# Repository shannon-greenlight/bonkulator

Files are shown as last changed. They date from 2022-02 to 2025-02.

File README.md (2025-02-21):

# Bonkulator
# The Bonkulator has been replaced by Thor's Arsenal

The Bonkulator is a Eurorack module that fits into a 3U x 14HP slot. It features 8 programmable outputs and 6 programmable inputs. The front-panel user controls consist of a 128×64 pixel 2-color OLED display, a rotary encoder for adjusting parameters and a button for each trigger and output.

# main_board, panel

These repos contain the materials needed to construct the Bonkulator main board and the front panel.
The files are for KiCAD 6.0. Go to the Greenlight Kicad repo to get the needed libraries.
The gerber files work with JLCPC and will most likely work with other board manufacturers.

Assembly instructions are in main_board\fab\bonkulator_assembly.docx.

When using the JLCPCB assembly service, the BOM is split into 3 parts.

- bom/lcsc/bonkulator_bom.xlsx : The parts to be assembled by JLCPCB
- bom/digi-key/bonkulator_bom.xlsx : The remaining parts to be assembled by user
- bom/other/other_bom.xlsx : The parts that must be bought from sources other than JLCPCB and Digi-Key

Also, when an assembly service is used, a component position file is required. This file's path is: fab/Bonkulator_cpl.xlsx

notes: The bom and cpl files are auto-generated from the csv BOM files produced by KiCAD. You will need to refresh the data when changes to the schematic that affect the BOM or changes to the board layout occur.
If they exist, the extra parts and additional data fields that appear on the schematic help to produce the different BOM files. They must be maintained for these BOMs to come out right.

# code

This repository contains the elements needed to build code for the Bonkulator.

# BonkDaddy

The Bonk Daddy is an addition to the Bonkulator that provides these benefits:

- Front Panel USB access
- Power sensing shuts off USB to Arduino when synth power is off
- Reset switch
- USB Power indicator
- Trig In indicators
- Boot Loader indicator
- Extremely useful to those who use Terminal Remote mode

The folder structure of the Bonk Daddy is similar to the Bonkulator Hardware folder, main_board. Currently there is no support for assembly service.

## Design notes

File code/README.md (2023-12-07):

# Bonkulator-Code

This repository contains the elements needed to build code for the Bonkulator.
The code is for the Arduino RP2040 Connect and is found in the code/Bonkulator folder. Make sure to get the required libraries from the Arduino-Libs repo.
The code package is designed to be stand-alone and work with any IDE. You don't need the Arduino IDE. However, it will work with the Arduino IDE if you want to use it.

Build files are provided for Windows and Mac.

Here is a list of the batch and shell files:

- make.bat, make.sh ... compiles the code
- make_n_load.bat, make_n_load.sh ... calls make then uploads the code to the Bonkulator
- load_recent.bat, load_recent.sh ... loads most recent compile
- list_ports.bat, list_ports.sh ... lists available COM ports
- release.bat, release.sh ... used to create release, updating the release number in the code and create zip archives in the releases folder

Folders:

- out ... this folder must be created. It holds compile output
- releases ... this folder contains all of the archived releases
- updater ... this folder contains files needed by users to update their modules. This is what is zipped into the archive files.
- bin ... this folder contains executables for the Mac
- Bonkulator ... folder where the code exists
- secrets_example ... copy this folder to code/Bonkulator and rename it: secrets. Edit secrets.h to enter your preferred WiFi network and password.

The Arduino libraries from the Arduino-Libs repo must be included. Put them in the code/Bonkulator folder in a folder named 'libraries'.
Copy the entire contents of Arduino-Libs, not the folder itself. You can clone the libraries directly.

1. Go to the code/Bonkulator folder and open a power shell if on Windows, or open a Terminal if you are on the Mac.
2. Type: git clone https://github.com/shannon-greenlight/Arduino-Libs.git
3. Rename the resulting Arduino-Libs folder : libraries.
4. Keep this folder up to date using: git pull.

If you are using a Mac, you must call the .sh files from a Terminal window. Use the form ./filename.sh to execute the .sh file.
Use the following instructions to open a Terminal window in the code folder:

1. Open Finder.
2. Navigate to the directory where you want to open the Terminal.
3. Click to select the folder.
4. From the menu bar at the top of the screen, click on Finder.
5. In the dropdown menu, hover over Services.
6. In the Services menu, click on New Terminal at Folder.

This will open a new Terminal window that's already navigated to the directory you selected in Finder. If you don't see the New Terminal at Folder option, you may need to enable it in System Preferences -> Keyboard -> Shortcuts -> Services.

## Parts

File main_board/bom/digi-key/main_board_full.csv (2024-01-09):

Reference | Quantity | Value | Digi-Key Part #
A1, | 1 | Arduino_Nano_RP2040_Connect | 1050-ABX00053-ND
C1, C2, | 2 | 100uF | 399-A768EB107M1ELAE036DKR-ND
C3, C4, C5, C6, C8, C9, C14, C15, C16, C17, C18, C19, C20, C21, C22, C23, C24, C25, C27, C28, C29, C30, C32, C33, C34, C35, C36, C37, C38, C39, C40, C41, C42, C52, C53, C54, C55, | 37 | 100nF | 478-10836-1-ND
C7, C31, C43, | 3 | 1uF | 1276-1029-1-ND
C11, C12, C13, C26, C44, C45, C46, C47, C48, C49, C50, C51, | 12 | 10nF | 311-1136-1-ND
D1, D2, D3, D4, D5, D6, D7, D8, D13, D14, D15, D16, D17, D18, D39, D40, D41, D42, D45, D46, | 20 | 1N5819 | 478-7800-1-ND
D9, D19, D20, D21, D22, D23, D24, D29, D30, D31, D32, | 11 | BLUE LED | 732-11401-ND
D10, | 1 | YELLOW LED | 732-5010-ND
D11, D25, D26, D27, D28, D33, D34, D35, D36, D37, D38, | 11 | RED LED | 732-5005-ND
D12, | 1 | GREEN LED | 732-5007-ND
D43, D44, | 2 | 7.5V | DDZ7V5CDICT-ND
J1, J2, J3, J4, J8, J9, J10, J11, J12, J13, J14, J15, J16, J17, | 14 | 3.5mm Jack | WM17366-ND
J5, | 1 | Display Header | SAM1011-04-ND
J6, | 1 | EU Power | S2011EC-05-ND
J7, | 1 | Expansion Header | S2011EC-05-ND
J18, J19, | 2 | Conn_01x15_Female | S7048-ND
J20, | 1 | Conn_01x02_Male | 609-4938-ND
J21, | 1 | OLED Pins | 732-5317-ND
N1, N2, N3, N4, N5, N6, | 6 | Nut | 36-4687-ND
Q1, | 1 | MMBT3904 | 4878-MMBT3904CT-ND
R1, R2, R3, R4, R32, R37, R38, R39, R56, R57, R66, R67, R68, R69, R70, R71, R72, R97, R98, R99, R100, R125, R126, R127, R128, R141, | 26 | 10K | 13-RC0805JR-1010KLCT-ND
R5, R6, R7, R8, | 4 | 1K | RNCP0805FTD1K00CT-ND
R9, | 1 | 200K .1% | P200KDACT-ND
R10, | 1 | 68K | 311-68KARCT-ND
R11, R12, R13, R14, R15, R16, R17, R18, R19, R40, R41, R42, R43, R44, R45, R46, R47, R61, R62, R63, R64, R65, R73, R74, R75, R78, R142, R143, | 28 | 100K .1% | YAG1759CT-ND
R20, R21, R22, R23, R48, R49, R50, R51, R58, | 9 | 33K | RMCF0805JT33K0CT-ND
R24, R25, R26, R27, R52, R53, R54, R55, | 8 | 332K .1% | P332KDACT-ND
R28, R33, | 2 | 30.1K .1% | P30.1KDACT-ND
R29, R31, R34, R36, | 4 | 10K .1% | P10KDACT-ND
R30, R35, | 2 | 4.7K | RMCF0805FT4K70CT-ND
R59, R60, | 2 | 680 | 311-680ARCT-ND
R76, R79, R80, R81, R82, | 5 | 1K | RNCP0603FTD1K00CT-ND
R77, | 1 | 23.7K 1% | RMCF0603FT23K7CT-ND
RV9, | 1 | 10K | 3224W-1-103GCT-ND
SC1, SC2, SC3, SC4, | 4 | Screw | 145-50M025045P006-ND
SO1, SO2, SO3, SO4, SO5, SO6, SO7, SO8, SO9, SO10, SO11, SO12, SO13, SO14, SO15, SO16, SO17, SO18, SO19, SO20, SO21, SO22, SO23, SO24, | 24 | LED_Standoff | 732-11607-ND
SO25, SO26, SO27, SO28, | 4 | Board Standoff | 732-13063-ND
SO29, SO30, | 2 | DisplayStandoff | 732-13055-ND
SW1, SW2, SW3, SW4, SW6, SW7, SW8, SW9, SW10, SW11, SW12, SW13, SW14, SW15, SW16, SW17, | 16 | Push Button | 450-1643-ND
SW5, | 1 | Adj | 987-1187-ND
TP1, TP2, | 2 | TestPoint | 36-5006-ND
TP3, TP4, | 2 | TestPoint | 36-5002-ND
U1, U4, U9, U10, U12, U14, U17, U18, | 8 | TL072CDR | 296-1282-1-ND
U2, U5, U8, U19, | 4 | TL072CDR | 296-1282-1-ND
U6, | 1 | AD5328 | 505-AD5328ARUZ-REEL7CT-ND
U11, | 1 | ADS1015IDGS | 296-25227-1-ND
U13, U24, | 2 | DG412DY-E3 | DG412DY-E3-ND
U15, | 1 | AS431HANTR | AS431HANTR-G1DICT-ND
U16, | 1 | MB85RC256 | 865-1261-1-ND
U21, | 1 | MCP23008-xSS | MCP23008-E/SS-ND

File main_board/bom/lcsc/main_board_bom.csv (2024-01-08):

Designator | Comment | Footprint | JLCPCBPart#
C1, C2, | 100uF | Capacitor_SMD:CP_Elec_6.3x5.4_Nichicon | C2887272
C3, C4, C5, C6, C8, C9, C14, C15, C16, C17, C18, C19, C20, C21, C22, C23, C24, C25, C27, C28, C29, C30, C32, C33, C34, C35, C36, C37, C38, C39, C40, C41, C42, C52, C53, C54, C55, | 100nF | Capacitor_SMD:C_0805_2012Metric_Pad1.18x1.45mm_HandSolder | C49678
C7, C31, C43, | 1uF | Capacitor_SMD:C_0805_2012Metric_Pad1.18x1.45mm_HandSolder | C28323
C11, C12, C13, C26, C44, C45, C46, C47, C48, C49, C50, C51, | 10nF | Capacitor_SMD:C_0805_2012Metric_Pad1.18x1.45mm_HandSolder | C1710
D1, D2, D3, D4, D5, D6, D7, D8, D13, D14, D15, D16, D17, D18, D39, D40, D41, D42, D45, D46, | 1N5819 | Diode_SMD:D_0805_2012Metric_Pad1.15x1.40mm_HandSolder | C191023
D43, D44, | 7.5V | Diode_SMD:D_SOD-123 | C545306
J6, | EU Power | Connector_PinHeader_2.54mm:PinHeader_2x05_P2.54mm_Vertical | C492422
J7, | Expansion Header | Connector_PinHeader_2.54mm:PinHeader_2x05_P2.54mm_Vertical | C492422
J18, J19, | Conn_01x15_Female | sputterizer:ArduinoConnector | C2932676
J20, | Conn_01x02_Male | Connector_PinHeader_2.54mm:PinHeader_1x02_P2.54mm_Vertical | C492401
Q1, | MMBT3904 | Package_TO_SOT_SMD:SOT-23 | C20526
R1, R2, R3, R4, R32, R37, R38, R39, R56, R57, R66, R67, R68, R69, R70, R71, R72, R97, R98, R99, R100, R125, R126, R127, R128, R141, | 10K | Resistor_SMD:R_0805_2012Metric_Pad1.20x1.40mm_HandSolder | C17414
R5, R6, R7, R8, | 1K | Resistor_SMD:R_0805_2012Metric_Pad1.20x1.40mm_HandSolder | C17513
R9, | 200K .1% | Resistor_SMD:R_0805_2012Metric_Pad1.20x1.40mm_HandSolder | C332260
R10, | 68K | Resistor_SMD:R_0805_2012Metric_Pad1.20x1.40mm_HandSolder | C17801
R11, R12, R13, R14, R15, R16, R17, R18, R19, R40, R41, R42, R43, R44, R45, R46, R47, R61, R62, R63, R64, R65, R73, R74, R75, R78, R142, R143, | 100K .1% | Resistor_SMD:R_0805_2012Metric_Pad1.20x1.40mm_HandSolder | C122537
R20, R21, R22, R23, R48, R49, R50, R51, R58, | 33K | Resistor_SMD:R_0805_2012Metric_Pad1.20x1.40mm_HandSolder | C17633
R24, R25, R26, R27, R52, R53, R54, R55, | 332K .1% | Resistor_SMD:R_0805_2012Metric_Pad1.20x1.40mm_HandSolder | C2681637
R28, R33, | 30.1K .1% | Resistor_SMD:R_0805_2012Metric_Pad1.20x1.40mm_HandSolder | C374678
R29, R31, R34, R36, | 10K .1% | Resistor_SMD:R_0805_2012Metric_Pad1.20x1.40mm_HandSolder | C406725
R30, R35, | 4.7K | Resistor_SMD:R_0805_2012Metric_Pad1.20x1.40mm_HandSolder | C17673
R59, R60, | 680 | Resistor_SMD:R_0805_2012Metric_Pad1.20x1.40mm_HandSolder | C17798
R76, R79, R80, R81, R82, | 1K | Resistor_SMD:R_0603_1608Metric | C21190
R77, | 23.7K 1% | Resistor_SMD:R_0603_1608Metric | C227724
RV9, | 10K | Potentiometer_SMD:Potentiometer_Bourns_3224W_Vertical | C81348
TP1, TP2, | TestPoint | TestPoint:TestPoint_Keystone_5005-5009_Compact | C2906764
TP3, TP4, | TestPoint | TestPoint:TestPoint_Keystone_5000-5004_Miniature | C238123
U1, U4, U9, U10, U12, U14, U17, U18, | TL072CDR | Package_SO:SOIC-8-1EP_3.9x4.9mm_P1.27mm_EP2.29x3mm | C6961
U2, U5, U8, U19, | TL072CDR | Package_SO:SOIC-8_3.9x4.9mm_P1.27mm | C6961
U6, | AD5328 | Package_SO:TSSOP-16_4.4x5mm_P0.65mm | C29162
U11, | ADS1015IDGS | Package_SO:TSSOP-10_3x3mm_P0.5mm | C193969
U13, U24, | DG412DY-E3 | Package_SO:SOIC-16_3.9x9.9mm_P1.27mm | C45218
U15, | AS431HANTR | Package_TO_SOT_SMD:SOT-23 | C460669
U16, | MB85RC256 | Package_SO:SOIC-8_3.9x4.9mm_P1.27mm | C47538
U21, | MCP23008-xSS | Package_SO:SSOP-20_5.3x7.2mm_P0.65mm | C148011

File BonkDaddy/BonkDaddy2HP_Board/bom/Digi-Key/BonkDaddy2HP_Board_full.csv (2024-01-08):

Reference | Quantity | Value | Digi-Key Part #
C1, C3, | 2 | 1uF | 1276-1066-1-ND
D1, | 1 | RED LED | 732-5005-ND
D2, D4, | 2 | GREEN LED | 732-5008-ND
D3, | 1 | YELLOW LED | 732-5010-ND
D5, | 1 | BLUE LED | 160-1035-ND
J1, | 1 | EXP | S2011EC-05-ND
J2, | 1 | USB_B_Micro | 2073-USB3131-30-0230-ACT-ND
J3, | 1 | USB_A | UE27AE54100-ND
N1, N2, | 2 | Nut | 36-4687-ND
Q3, | 1 | 2N7002 | 4878-2N7002CT-ND
Q4, | 1 | MMBT3906 | MMBT3906LT1GOSCT-ND
R1, R2, R4, R5, | 4 | 620 | RMCF0805FT620RCT-ND
R3, | 1 | 1K | 311-1.00KCRCT-ND
R6, R9, | 2 | 10K | RMCF0805FT10K0CT-ND
R7, R8, | 2 | 30K | RMCF0805FT30K0CT-ND
SC1, SC2, | 2 | Screw | 145-50M025045G004-ND
SO1, SO2, | 2 | Stand-off | 1772-2756-ND
SW1, | 1 | Reset | 450-1940-ND
U1, | 1 | 74AHC14 | 296-9179-1-ND
W1, W2, | 2 | Washer | RPC3448-ND

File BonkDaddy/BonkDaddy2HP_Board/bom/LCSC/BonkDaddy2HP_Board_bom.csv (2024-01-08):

Designator | Comment | Footprint | JLCPCBPart#
C1, C3, | 1uF | Capacitor_SMD:C_0805_2012Metric | C28323
J1, | EXP | Connector_PinHeader_2.54mm:PinHeader_2x05_P2.54mm_Vertical_SMD | C124391
J3, | USB_A | sputterizer:USB_A_Amphenol_UE27AE54100_Vertical | C386737
Q3, | 2N7002 | Package_TO_SOT_SMD:SOT-23 | C8545
Q4, | MMBT3906 | Package_TO_SOT_SMD:SOT-23 | C266589
R1, R2, R4, R5, | 620 | Resistor_SMD:R_0805_2012Metric_Pad1.20x1.40mm_HandSolder | C17782
R3, | 1K | Resistor_SMD:R_0805_2012Metric_Pad1.20x1.40mm_HandSolder | C17513
R6, R9, | 10K | Resistor_SMD:R_0805_2012Metric_Pad1.20x1.40mm_HandSolder | C17414
R7, R8, | 30K | Resistor_SMD:R_0805_2012Metric_Pad1.20x1.40mm_HandSolder | C17621
U1, | 74AHC14 | Package_SO:SOIC-14_3.9x8.7mm_P1.27mm | C5605

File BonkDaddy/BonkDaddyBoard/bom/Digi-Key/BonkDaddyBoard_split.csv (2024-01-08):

Reference | Quantity | Value | Digi-Key Part #
D1, | 1 | RED LED | 732-5005-ND
D2, D4, | 2 | GREEN LED | 732-5008-ND
D3, | 1 | YELLOW LED | 732-5010-ND
D5, | 1 | BLUE LED | 160-1035-ND
J2, | 1 | USB_B_Micro | 2073-USB3131-30-0230-ACT-ND
N1, N2, N3, N4, | 4 | Nut | 36-4687-ND
SC1, SC2, SC3, SC4, | 4 | Screw | 145-50M025045G004-ND
SO1, SO2, SO3, SO4, | 4 | Stand-off | 1772-2756-ND
SW1, | 1 | Reset | 450-1940-ND
U1, | 1 | 74HC14 | TC74HC14APF-ND
W1, W2, W3, W4, | 4 | Washer | RPC3448-ND

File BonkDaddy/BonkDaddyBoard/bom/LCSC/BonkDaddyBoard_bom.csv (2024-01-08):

Designator | Comment | Footprint | JLCPCBPart#
C1, C3, | 1uF | Capacitor_THT:C_Rect_L7.0mm_W2.0mm_P5.00mm | C94708
J1, | EXP | Connector_PinHeader_2.54mm:PinHeader_2x05_P2.54mm_Vertical | C225520
J3, | USB_A | sputterizer:USB_A_Amphenol_UE27AE54100_Vertical | C386737
Q3, | 2N7000 | Package_TO_SOT_THT:TO-92_Inline_Wide | C232838
Q4, | 2N3906 | Package_TO_SOT_THT:TO-92_Inline_Wide | C9809
R1, R2, R4, R5, | 620 | Resistor_THT:R_Axial_DIN0207_L6.3mm_D2.5mm_P10.16mm_Horizontal | C120050
R3, | 1K | Resistor_THT:R_Axial_DIN0207_L6.3mm_D2.5mm_P2.54mm_Vertical | C120055
R6, R9, | 10K | Resistor_THT:R_Axial_DIN0207_L6.3mm_D2.5mm_P10.16mm_Horizontal | C433778
R7, | 30K | Resistor_THT:R_Axial_DIN0207_L6.3mm_D2.5mm_P2.54mm_Vertical | C176499
R8, | 30K | Resistor_THT:R_Axial_DIN0207_L6.3mm_D2.5mm_P10.16mm_Horizontal | C176499
U1, | A_14-LC-TT | Package_DIP:DIP-14_W7.62mm_Socket | C132508

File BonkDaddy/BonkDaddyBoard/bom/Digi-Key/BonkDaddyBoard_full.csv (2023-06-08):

Reference | Quantity | Value | Digi-Key Part #
C1, | 1 | .1uF | 399-9877-2-ND
C2, C3, | 2 | 10uF | P980-ND
D1, | 1 | RED LED | 732-5005-ND
D2, D4, | 2 | GREEN LED | 732-5008-ND
D3, | 1 | YELLOW LED | 732-5010-ND
D5, | 1 | BLUE LED | 160-1035-ND
J1, | 1 | EXP | S2011EC-05-ND
J2, | 1 | USB_B_Micro | 2073-USB3131-30-0230-ACT-ND
J3, | 1 | USB_A | UE27AE54100-ND
N1, N2, N3, N4, | 4 | Nut | 36-4687-ND
Q3, | 1 | 2N7000 | 2N7000BU-ND
Q4, | 1 | 2N3906 | 2N3906TFCT-ND
R1, | 1 | 100 | CF14JT100RCT-ND
R2, | 1 | 75 | CF14JT75R0CT-ND
R3, | 1 | 1K | 738-CFF14JT1K00CT-ND
R4, | 1 | 68 | CF14JT68R0CT-ND
R5, | 1 | 47 | CF14JT47R0CT-ND
R6, R9, | 2 | 10K | CF14JT10K0CT-ND
R7, R8, | 2 | 43K | CF14JT43K0CT-ND
SC1, SC2, SC3, SC4, | 4 | Screw | 145-50M025045G004-ND
SK1, | 1 | A_14-LC-TT | AE9989-ND
SO1, SO2, SO3, SO4, | 4 | Stand-off | 1772-2756-ND
SW1, | 1 | Reset | 450-1940-ND
U1, | 1 | 74AHC04 | 296-12772-5-ND
W1, W2, W3, W4, | 4 | Washer | RPC3448-ND

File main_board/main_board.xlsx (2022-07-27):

Reference | Quantity | Value | Footprint | LCSC Part #
C1 C2 | 2 | 100uF | Capacitor_SMD:CP_Elec_6.3x5.4_Nichicon | C2887276
C11 C12 C13 C26 | 4 | 10nF | Capacitor_SMD:C_0805_2012Metric_Pad1.18x1.45mm_HandSolder | C83170
C3 C4 C5 C6 C8 C9 C14 C15 C16 C17 C18 C19 C20 C21 C22 C24 C25 C27 C28 C30 C32 C33 C34 C35 C36 C37 C38 C39 C40 C41 C42 | 31 | 100nF | Capacitor_SMD:C_0805_2012Metric_Pad1.18x1.45mm_HandSolder | C49678
C7 C10 C31 C43 | 4 | 330nF | Capacitor_SMD:C_0805_2012Metric_Pad1.18x1.45mm_HandSolder | C107132
D1 D2 D3 D4 D5 D6 D7 D8 D13 D14 D15 D16 D17 D18 | 14 | BAT46 | Diode_SMD:D_0805_2012Metric_Pad1.15x1.40mm_HandSolder | C123899
J18 J19 | 2 | Conn_01x15_Female | sputterizer:ArduinoConnector | C124408
J6 | 1 | EU Power | Connector_PinHeader_2.54mm:PinHeader_2x05_P2.54mm_Vertical | C115170
J7 | 1 | Expansion Header | Connector_PinHeader_2.54mm:PinHeader_2x05_P2.54mm_Vertical | C115170
Q1 | 1 | MMBT3904 | Package_TO_SOT_SMD:SOT-23 | C94514
R1 R2 R3 R4 R32 R37 R66 R67 R68 R81 R82 R83 R84 R93 R94 R95 R96 R109 R110 R111 R112 R121 R122 R123 R124 R125 R126 R127 R128 R133 R134 R139 R140 | 33 | 10K | Resistor_SMD:R_0805_2012Metric_Pad1.20x1.40mm_HandSolder | C138260
R10 | 1 | 68K | Resistor_SMD:R_0805_2012Metric_Pad1.20x1.40mm_HandSolder | C137412
R11 R12 R13 R14 R15 R16 R17 R18 R19 R40 R41 R42 R43 R44 R45 R46 R47 R142 R143 | 19 | 100K .1% | Resistor_SMD:R_0805_2012Metric_Pad1.20x1.40mm_HandSolder | C122537
R73 R74 R75 R76 R101 R102 R103 R104 R129 R130 | 10 | 750K | Resistor_SMD:R_0805_2012Metric_Pad1.20x1.40mm_HandSolder | C137408
R77 R78 R79 R80 R105 R106 R107 R108 R131 R132 | 10 | 3.32M | Resistor_SMD:R_0805_2012Metric_Pad1.20x1.40mm_HandSolder | C422748
R85 R86 R87 R88 R113 R114 R115 R116 R135 R136 | 10 | 2.2K | Resistor_SMD:R_0805_2012Metric_Pad1.20x1.40mm_HandSolder | C26017
R89 R90 R91 R92 R117 R118 R119 R120 R137 R138 | 10 | 1K | Resistor_SMD:R_0805_2012Metric_Pad1.20x1.40mm_HandSolder | C100047
R141 | 1 | 20K | Resistor_SMD:R_0805_2012Metric_Pad1.20x1.40mm_HandSolder | C237133
R20 R21 R22 R23 R48 R49 R50 R51 | 8 | 43K | Resistor_SMD:R_0805_2012Metric_Pad1.20x1.40mm_HandSolder | C137429
R24 R25 R26 R27 R52 R53 R54 R55 | 8 | 332K .1% | Resistor_SMD:R_0805_2012Metric_Pad1.20x1.40mm_HandSolder | C228750
R28 R33 | 2 | 30.1K .1% | Resistor_SMD:R_0805_2012Metric_Pad1.20x1.40mm_HandSolder | C374678
R29 R31 R34 R36 | 4 | 10K .1% | Resistor_SMD:R_0805_2012Metric_Pad1.20x1.40mm_HandSolder | C406725
R30 R35 | 2 | 4.3K | Resistor_SMD:R_0805_2012Metric_Pad1.20x1.40mm_HandSolder | C229218
R38 R39 R69 R70 R71 R72 R97 R98 R99 R100 | 10 | 1.00M | Resistor_SMD:R_0805_2012Metric_Pad1.20x1.40mm_HandSolder | C107700
R5 R6 R7 R8 | 4 | 300 | Resistor_SMD:R_0805_2012Metric_Pad1.20x1.40mm_HandSolder | C134081
R9 | 1 | 200K .1% | Resistor_SMD:R_0805_2012Metric_Pad1.20x1.40mm_HandSolder | C473320
U1 U2 U4 U8 U9 U10 U12 U14 U17 U18 U19 | 11 | TL072CDR | Package_SO:SOIC-8-1EP_3.9x4.9mm_P1.27mm_EP2.29x3mm | C67473
U11 | 1 | ADS1015IDGS | Package_SO:TSSOP-10_3x3mm_P0.5mm | C193969
U15 | 1 | LM4132xMF-3.3 | Package_TO_SOT_SMD:SOT-23-5 | C181258
U16 | 1 | MB85RC256 | Package_SO:SOIC-8_3.9x4.9mm_P1.27mm | C47538
U5 | 1 | TL072CDR | Package_SO:SOIC-8_3.9x4.9mm_P1.27mm | C67473
U6 | 1 | AD5328 | Package_SO:TSSOP-16_4.4x5mm_P0.65mm | C29162
U7 | 1 | L78L05_SOT89 | Package_TO_SOT_SMD:SOT-89-3 | C90471

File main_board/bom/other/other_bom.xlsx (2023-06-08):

Reference | Quantity | Value | URL
M1 | 1 | OLED | https://www.amazon.com/gp/product/B072Q2X2LL/

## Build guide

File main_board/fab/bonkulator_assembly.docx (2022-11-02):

# Bonkulator Assembly Instructions

The Bonkulator uses components on both sides of the board. Because of this, the order of assembly is important. Also, the order is intended to add components like the push buttons near the end of the process so they will not risk being damaged by the hot iron.

The top side assembly procedure is broken into 3 parts to make it easier to align the components. It is possible to do in fewer steps. It’s up to the builder to decide if consolidation would be beneficial.

Because of the density of the circuitry, a conical .8mm tip soldering iron is suggested.

Difficulty: intermediate. Not recommended for first SMT build.

1. Install 4 12mm stand-offs to the front panel using screws. Set this aside for later.
2. Install all SMT components.
3. Install headers J6, J7, J18, J19 and J20.
4. Install test points TP1, TP2 and TP3.
5. This completes assembly of bottom side. Aside from the test points, this also is what is delivered from JLCPCB when using their assembly service.
6. Install display header J5.
7. Trim the leads of J18 that will impede proper placement of J9.
8. Install rotary encoder and jacks:
  a. Place rotary encoder SW5 into board.
  b. Place jacks J1, J2, J3, J4, J8, J9, J10, J11, J12, J13, J14, J15, J16 and J17 into board.
  c. Temporarily assemble front panel to board to assure proper alignment of components.
  d. Solder components and remove front panel.
9. Install push buttons:
  a. Place Push buttons SW1, SW2, SW3, SW4, SW6, SW7, SW8, SW9, SW10, SW11, SW12, SW13, SW14, SW15, SW16 and SW17 into board.
  b. Temporarily assemble front panel to board to assure proper alignment of components.
  c. Solder components and remove front panel.
10. Install display and LEDs:
  a. Install display.
    i. Install display standoffs into board. Be careful to avoid damaging parts that may lie below the nylon nut (early rev boards).
    ii. Solder header to display and trim leads flush with display board. Insert display into J5.
    iii. Use wooden, round toothpicks to align display on standoffs. Insert toothpick from top and trim flush with display surface. (No standoffs were available that matched hole size on the display)
  b. Place LEDs using LED standoffs.
  c. Assemble front panel to board to assure proper alignment of components. This should be final assembly, OK to use all 4 nuts.
  d. Solder LEDs.
11. Install Arduino on the back side of the board.
12. Attach knobs
13. That’s all! You’re ready to test and calibrate.

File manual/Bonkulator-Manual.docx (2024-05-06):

# The Bonkulator

User Manual

Greenface Labs -- 2024

# Description

The Bonkulator is a 14HP Eurorack module that generates signals that can be used to modulate voltage-controlled functions such as VCO, VCF, VCA, etc... Eight independent outputs can be triggered by any of four trigger inputs and can also be modulated by the two input signals. In addition to the front panel controls, the Bonkulator provides a Web interface via WiFi and desktop and Terminal interfaces via USB. These interfaces enhance the user experience and bring a greater level of controllability to the module.

#### 8 Outputs

- In general, the output value follows a selected shape.
- Shapes can be from the factory list or user defined.
- Factory shapes include ramp-up, ramp-down, sine, haystack and others.
- Outputs can be programmed to be triggered or clocked by any of the trigger inputs.
- Outputs can be scaled by UI setting or by CV input.
- Outputs can be offset by UI setting or by CV input.
- Output period can be set via UI or by CV input.
- Output repetitions can be set from 1 to 65,535.
- Output quantization can be enabled or disabled.
- Output can be randomized from 0-99%.
- Outputs have LED level indicators

#### 4 Trigger/Clock Inputs

- Triggers activate output functions.
- When Output is set to Ext Clk mode, trigger inputs increment the shape step.
- The trigger inputs respond to a positive-going signal or a button press.
- Each trigger can be independently enabled or disabled.
- An LED indicates when any attached output is active.

#### 2 CV Inputs

- +/-5V input range.
- CV inputs can control many of the output parameters.
- LED level indicators.

# Installation

Care must be taken to connect the power to the right connector. The power connection is “either way”. Refer to the following image for the location of the power connector.

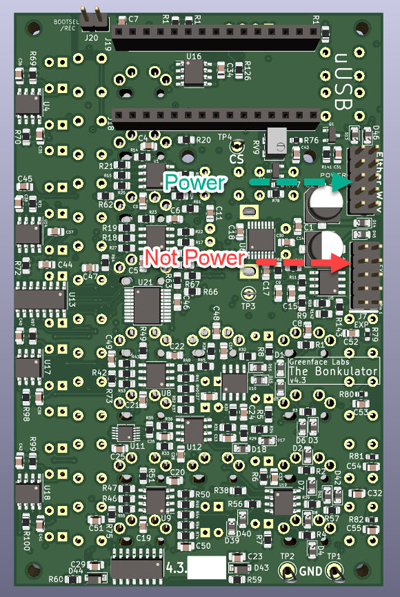
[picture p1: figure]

# Quick Start

The Bonkulator can be used in an endless variety of ways, but here is a great way to start exploring. These instructions are for use with a Moog Mother-32 but can be easily adapted to most modular synthesizers. Addition of an Echo module is highly recommended.

#### Mother-32 Set-up

- VCA Mode – ON (do not use the envelope generator)
- VCO Mod Amount – 50%
- VCO Mod Dest - Frequency
- VCF Mode – Low Pass
- VCF Mod Polarity – +
- LFO Wave – triangle
- LFO Rate – 30%
- Cutoff – 50%
- Resonance – 20%
- Sustain – Off
- Frequency – 50%
- Pulse Width – 50%
- VCO Wave - Pulse
- Octave – 4
- Note – 8

#### Bonkulator Set-Up

- Both (common settings)
  - Waveform: Ramp
  - Init Delay: 00000
  - Active Time: 03010
  - Idle Time: 00000
  - Repeat: 00000
  - T0: Enabled
  - T1: Disabled
  - T2: Disabled
  - T3: Disabled
  - CV0: Off
  - CV1: Off
  - Scale: see below
  - Offset: 000
  - Randomness: 00
  - Quantize: No
  - Idle Value: 2048
  - Clock: Internal
  - Range: +/-5V
- Output 0
  - Scale: 100
- Output 1
  - Scale: -100

Connect the Bonkulator Output 0 to the M-32 VCO 1V/Oct input and the VCF Cutoff input. Connect Output 1 to the M-32 LFO Rate input. Press Trigger 0 on the Bonkulator and you should hear a sound much like that found here (https://www.greenfacelabs.com/wp-content/uploads/2022/07/bonkulator_quick_start.mp3). Experiment with the various Output parameters. Try increasing the Randomness on Output 0 to 20.

# Overview

The Bonkulator is a Eurorack module that fits into a 3U x 14HP slot. It features 8 programmable outputs and 6 programmable inputs. The front-panel user controls consist of a 128×64 pixel 2-color OLED display, a rotary encoder and arrow buttons for adjusting parameters. There is also a button for each trigger and output.

Pressing the output buttons brings up the configuration menu for each output. Outputs have many parameters. Among them are the Waveform to be sent and its Active Time. Select which triggers activate the output in the Output configuration menu. Complete information on all the parameters can be found in the Output Details section of this document.

Pressing the Adjust Knob activates various functions of the Bonkulator. The use of this button is context-sensitive and is only active within the Settings function. Pressing and holding this knob for longer than 2 seconds brings up the Settings function.

In addition to the front panel controls, the Bonkulator provides WiFi, Desktop and Terminal interfaces. The WiFi interface is a REST API and the Terminal interface is ANSI X3.64 via the Arduino micro-USB connector. The desktop interface is similar to WiFi except that it connects via USB. These interfaces greatly extend the usefulness and capabilities of the Bonkulator. Scripting, patch management, dedicated GUIs and even Internet-connected IoT apps are now possible. And using a remote interface means that you no longer have to adjust tiny dials amid a forest of patch cords. This benefit cannot be fully appreciated until it is experienced directly.

## Signals

- Outputs (8) – Analog signal (+/- 5 volt or 0-10V). Built-in and programmable waveforms.
- Triggers (4) – Digital signal that is activated by a 0 to +5V transition.
- CV (2) – Analog signal input. Range: +/- 5 volt

## Functions

- Output (0-7) – For configuring the 8 outputs
- Settings – For module configuration, WiFi , factory reset, etc.

## Controls

- Output Buttons (0-7) – For selecting from the 8 outputs
- Trigger Buttons (0-3) – For manual triggering
- Move Buttons (^v<>) – For navigating the display.
- Adjust Rotary Encoder – For adjusting selected parameter
- Activate Push Button – Push the Adjust knob to activate functions
- More controls are available via the remote interfaces

## Features

- A 128x64 two-color OLED graphic display enhances usability
- Web, Desktop and Terminal interfaces provide rich user experiences with the addition of computer resources like a keyboard, mouse, display and scripting.
- All settings are stored in FRAM memory so that they are retained when power is off
- Inputs and Outputs are protected against damage during typical use
- Output and Input LED indicators show voltage levels present at the jacks
- Trigger Indicator LEDs show if any Outputs have been activated by that trigger
- Output range is switchable: +/-5V or 0-10V (board models 4.0 and later)
- An Expansion module is available that provides an external USB interface with some interesting extra features. See “The BonkDaddy”.

## Front Panel

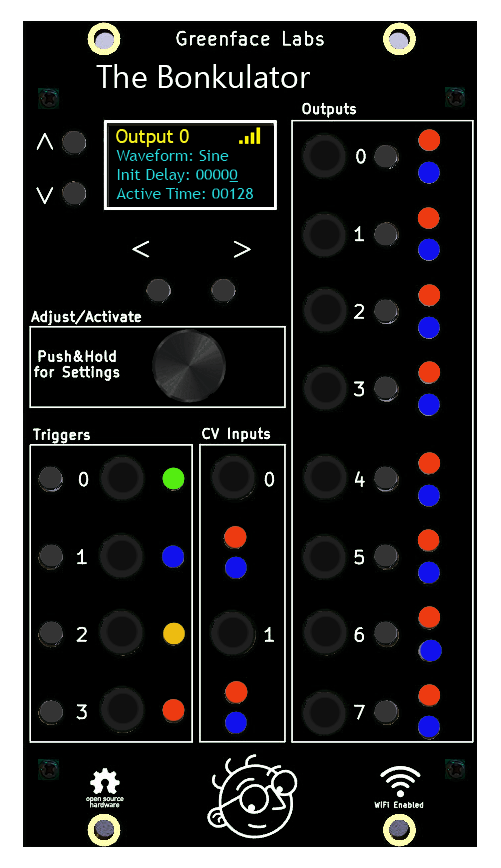
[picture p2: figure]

Figure 1 - Front Panel

## Open-Source Project

The Bonkulator is an Open-Source project that has an Arduino RP2040 at its core. The code is written in C++ and makes use of several public domain code libraries for managing the various purchased hardware components such as the display and the FRAM non-volatile memory.

Because it is Open Source, in addition to being used by musicians and sound designers to create new and amazing sounds, the Bonkulator can be used by students and entrepreneurs to create new, amazing modules. And, of course, the open-source community will generally improve the product as time goes along. Links to the design repositories can be found on the Bonkulator web page.

# Operation

## General Operation

The typical procedure for using the Bonkulator involves choosing a set of waveforms that are needed for a particular application. Then a set of triggers are defined and the various parameters for each waveform are entered. Once configured, the Bonkulator reacts to trigger signals, sending the waveform for each Output that was triggered.

- The Output is selected using the Output buttons.
  - Terminal uses the ‘f’ command.
  - Web Interface has dedicated Function buttons.
  - Each Output has several parameters.
  - Waveforms are selected as one of the parameters
  - Choose from 7 pre-installed waveforms and 8 user-defined waveforms.
- Parameters are adjusted using the arrow keys and the Adjust knob.
  - Parameters are selected using the up and down arrows.
  - Digit to be adjusted is selected by using the right and left arrows.
  - When entering strings, holding the right or left arrow down for 2 seconds inserts (right) or deletes (left) a character.
  - Use the Adjust knob to increment and decrement the selected digit.
  - Parameter values may be directly entered using the Terminal or Web Interface.
- Enable Triggers for each Output that is to be used
  - Outputs can be triggered by any or all of the four triggers.
  - Triggers T0 – T3 can be either ENABLED or DISABLED. They are set as above.
- Operation of each Output is triggered by a variety of methods.
  - Pressing the selected trigger button. (Manual trigger)
  - Receiving a low to high transition on the selected Trigger jack.
  - Terminal uses the ‘!’ key to trigger the selected trigger.
  - Web Interface has a dedicated Trigger button for each trigger.
- If an Output is already active, receiving a trigger command will re-trigger the output.
  - Trigger signals merely advance the waveform when in External Clock mode.
- Many parameters can be modulated by the two input signals.
  - Set CV0 and CV1 to select the modulation target (scale, offset, active time, idle value, randomness or off).
  - CV In jacks have a range of -5V to +5V
  - The sample period for the CV inputs is approximately 20ms. There is no filtering at the input to the converter, so frequencies above 5Hz will produce unpredictable modulation. Could be interesting…
  - If both CVs are specified, the effect is to cascade CV1 after CV0

## Screen Saver

In order to maximize display life, the display will turn off after a set time. The default time is 15 minutes. The time can be set in the Settings function with a range of 1 to 9999 minutes.

Press any button or send the ‘z’ command to bring the display back.

# Output Details

The Output signal ranges from -5.33V to +5.33V or from 0 to 10.66V. (see Range setting)

When the Output isn’t active, the Idle Value is sent. Use Output parameters to select the Idle Value.

Web mode has a dedicated slider control for several parameters, and Terminal mode uses the S, O and c keys followed by a number. See the table of remote commands for more details.

The Bonkulator Outputs have several parameters. Details for each parameter follow. A star(*) next to the name indicates that output is not calibrated.

1. Waveform – These are the signals that can be assigned to the outputs
  a. Fifteen waveforms are available, seven are factory-installed and eight are user-defined. Waveforms are stored as 128 values that range from 0-1023. Depending on the chosen Active Time, 10 to 128 of these values will be used to create the output signal.
  b. The factory-installed waveforms are: Sine, Haystack, Ramp, Pyramid, Pulse, Maytag, and Toggle.
  c. The user-defined waveforms can be entered by the following methods:
    i. Manually via the front panel controls
    ii. Via script using either Terminal mode or a Web Interface macro
    iii. Recorded from the CV0 input
2. Init Delay – The time in milliseconds to delay before sending the Waveform
  a. Range 0 to 65535 msecs
3. Active Time/Parts – The length in milliseconds of the waveform when in Internal clock mode or the number of samples to be used when in External clock mode
  a. Active Time ranges from 10 msecs – 65535 msecs
  b. Parts ranges from 10 to 128
  c. When in Internal clock mode, the Active Time affects the number of samples used and thus the sample rate.
    i. When the Active Time is a multiple of 128, the number of samples used will be the full 128.
    ii. When the Active Time is less than 128, the number of samples will equal the Active Time.
    iii. When the Active Time is greater than 128, the number of samples will be the result of a best-fit algorithm.
  d. When in External clock mode, the Delay and Repeat settings are ignored
4. Idle Time – The time in milliseconds to delay before repeating the Waveform
  a. Range 0 to 65535 msecs
5. Repeat – The number of times to repeat the waveform
  a. Range 1 to 65535
  b. Set Repeat to 0 to repeat forever.
6. T0 thru T4 – These are the Trigger/Clock inputs
  a. Each of the four triggers can be either Enabled or Disabled. That means that every output can be triggered by as many as four different trigger signals.
  b. Each trigger can be manually activated by pressing the associated button.
  c. Triggers are activated by a rising edge 5V signal at the input.
  d. In Internal clock mode, triggers re-trigger the trigger state of the output. So, if an output is Idle, receiving a trigger will activate the output. If the output is already active, a trigger will start sending the waveform from the beginning.
  e. When in External clock mode, every trigger merely sends the next output sample.
7. CV0 & CV1 – These are the control voltage inputs.
  a. They can be set to modulate the following Output parameters:
    i. Scale – Range .01x – 100x
      1. -5 V = .01x
      2. 0V = 1x
      3. 5V = 100x
    ii. Offset – Range +/-10.66V
      1. Output is offset by 2.13 times the input voltage.
    iii. Active Time – Range .1x thru 10x
    iv. Idle Value
    v. Randomness
  b. A star (*) next to the name indicates that input is not calibrated.
  c. Additionally, a change to the CV input can cause a trigger. Select Trigger as the CV target to do this.
8. Scale
  a. Full scale signal is +/-5.33V or 0-10V depending on Output Range setting
  b. Scale ranges from -100% to 100%
  c. Negative values invert the signal
9. Offset
  a. Range - +/-100%
  b. 100% = 10.66V
10. Randomness – 0 to 100%
11. Quantize - Yes/No
12. Idle Value
  a. The Idle Value is sent when the Output is not active.
  b. It is also sent during the Idle Time period.
  c. Idle Value of 0 corresponds to Output voltage of -5.33V
  d. Idle Value of 4095 corresponds to Output voltage of 5.33V
  e. Idle Value of 2048 corresponds to Output voltage of 0.0V
13. Clock
  a. Internal – The next sample is sent based on the Active Time setting.
  b. External – The next sample is sent on the rising edge of the enabled trigger.
14. Range
  a. +/-5V (Default)
  b. 0-10V (board models 4.0 and later)
15. Trigger Control
  a. Trigger Hold-off
    i. Suppresses triggers for set time after receiving a trigger.
    ii. Range 0-65535ms
  b. Trigger Skip
    i. Skips set number of triggers
    ii. Range 0-65535ms
  c. Trigger Density
    i. Randomly accepts a percentage of triggers
    ii. Range 0-100%

# Waveform Details

The Bonkulator has seven factory-installed and eight user-defined waveforms. The user-defined waveforms are managed in the Settings section where the initial names shown below may be changed.

1. Sine – Classic Sine Wave
2. Haystack – First half of Sine wave
3. Ramp – Asymmetrical sawtooth
4. Pyramid – Symmetrical sawtooth
5. Pulse – The Pulse is formed by the waveform transitioning from the Active Value to the Idle Value
  a. Idle Time must be non-zero for a pulse to form
  b. Offset is disabled for this waveform
  c. A variety of pulse shapes can be formed by adjusting Scale and Idle Value
6. Maytag – A random sequence
7. Toggle – Toggle creates a scaled and offset square wave that toggles with every transition of the trigger input
8. User Wave 0-7
  a. User Waves are managed in Settings
  b. Default is flat line
  c. User Waves can be manually entered point-by-point or recorded at CV0

# Settings Details

The Settings function displays information about the Bonkulator as well as allowing some adjustments to various system parameters. Refer to the table below.

Parameter | Min | Max | Sub Menu
Version | -- | --
Name | -- | --
Encoder Type | Normal | Reverse
WiFi | Enabled | Disabled | Press Activate
Screen Saver | 1 | 9999
Waveforms | Wave 0 | Wave 7 | Press Activate
Reset | -- | -- | Press Activate
Calibrate | Inputs | Outputs | Press Activate
Bounce | 0 | 1 | Press Activate

Notes:

1. Version shows the software version number. This is useful when communicating about bugs and questions.
2. Name
  a. The Name is displayed on boot-up and is displayed in the remote screens.
  b. This helps keep track of which unit is associated with which screen when there are multiple units installed.
3. Encoder Type takes the two types of rotary encoder into account. This makes them easier to purchase if one type is unavailable. If your Adjust knob is working opposite as it should, this is the setting that corrects it.
4. WiFi can be disabled here if you want to turn it off but retain your password.
5. Screen Saver prolongs the life of the OLED display. The screen will blank after the set number of minutes. Press any button to bring the display back.
6. Waveforms is where User Waveforms are managed. Each waveform contains 128 samples. Waveforms can be entered manually, drawn or imported using WiFi or the Desktop app, or recorded from CV0. Press Activate after selecting the waveform to bring up the Manage Waveform menu.
  a. Name – Enter a meaningful name for your waveform
  b. Index – For manual entry. Range 0:128
  c. Value – For manual entry. Range 0:4095 (see Output Range)
    i. Displays current value at the element pointed to by Index.
    ii. New values are entered by pressing Activate.
    iii. Pressing Activate also increments Index.
    iv. Value of 0 corresponds to negative full scale
    v. Value of 4095corresponds to positive full scale
    vi. Value of 2048 corresponds to mid scale
  d. Sample Time – This is the time between samples in milliseconds. Calculate using this formula: length of waveform to be sampled in milliseconds / 128
  e. Record On – The event that starts the recording of a waveform
    i. Immediate – Starts recording when Activated
    ii. Trigger – Waits for a trigger on any trigger input
    iii. +Change - Waits for a positive change in the voltage to start recording
    iv. -Change - Waits for a negative change in the voltage to start recording
  f. Note – The WiFi interface allows for point and click setting of the Index and Value. This greatly speeds up entering new waveforms.
7. Reset brings the Bonkulator’s parameters back to their factory defaults. Note that WiFi parameters are unaffected.
  a. Parameters
  b. Input Corrections
  c. Output Corrections
  d. All
8. Calibrate is where the 8 output and 2 input signal paths are calibrated.
  a. Inputs – Requires DC voltage source, accuracy .1%
    i. First apply 0VDC to input and adjust Offset to get a correct reading.
    ii. Apply 4VDC to input and adjust Scale to get a correct reading.
    iii. Test other voltages to verify accuracy. (note that full scale is +/-4.967V)
    iv. Set Calibrated to Yes when done.
  b. Outputs – Requires DC Voltmeter, accuracy .1%
    i. Adjust Offset until voltage at Output is as close to zero as possible.
    ii. Adjust Scale until voltage at Output is as close to 5.333 as possible.
    iii. Set Calibrated to Yes when done.
9. Bounce Function – An advanced Sample & Hold + DVM (see below)

# Bounce Function

The Bounce function measures the voltage present at the selected CV Input when triggered and displays it to the user. It also scales and offsets the measured voltage and “bounces” the result to the selected output.

This creates a scalable sample and hold function.

All the triggering modes apply.

The Bounce function is accessed via the Settings menu.

# Remote Modes

## WiFi

The Bonkulator is equipped with a 2.4GHz WiFi interface. When connected to your network, you can control the Bonkulator using the Web Interface (https://www.greenfacelabs.com/bonkulator-control/) (see example screen below).

WiFi can be disabled in the Settings function. Make sure it is enabled before proceeding in the connection process.

#### Connecting to WiFi

1. Enter WiFi function and press Activate to scan for networks.
2. Use the up and down arrow keys to select your network. Press Activate.
3. Use the right and left arrow keys with the Adjust control to select each character of your password. Press Activate when your password is entered. Note: It is much easier in Terminal mode. Type your password preceded by $, then press Enter.

The Bonkulator will try to connect using the password that you entered. If successful, the screen will display the connection data. This includes the connection status, the IP it can be found at and the signal strength. The signal strength will also be displayed in the upper right corner of the display as 1-4 bars. The signal strength display is shown in most functions.

If the connection fails, the Bonkulator will give its best explanation of why it failed.

The Bonkulator remembers its connection and will reestablish it if the power is recycled.

Visiting the WiFi function again while connected will display the connection data. Press Activate to re-enter the scan for networks screen.

If the Bonkulator connects to the network, but the Web app has trouble connecting to the Bonkulator, it often helps to recycle the power to the Bonkulator. Try the Web app again after the Bonkulator restarts and re-connects to WiFi.

Important: The Bonkulator only operates via http: Browsers often try to force https: For this reason, it is necessary to remove the ‘s’ from the URL in the address bar of your browser.

Figure 2 Chrome Browser

#### Using WiFi

The Bonkulator’s Web Interface was designed to emulate the physical front panel. However, because the Web Interface enjoys the added functionality a computer brings, it has significant differences. Please refer to Fig. 3 below.

While you can still adjust parameters a digit at a time, you can now enter parameters from the keyboard by first clicking on the parameter then using the dedicated entry field.

Adjusting parameters digit by digit is possible by using the right and left arrows to select the digit and using the Inc and Dec buttons to increment and decrement the digit.

When entering User Waveforms, you can click on the graph to set the Index or Value. This saves a lot of time over manual entry.

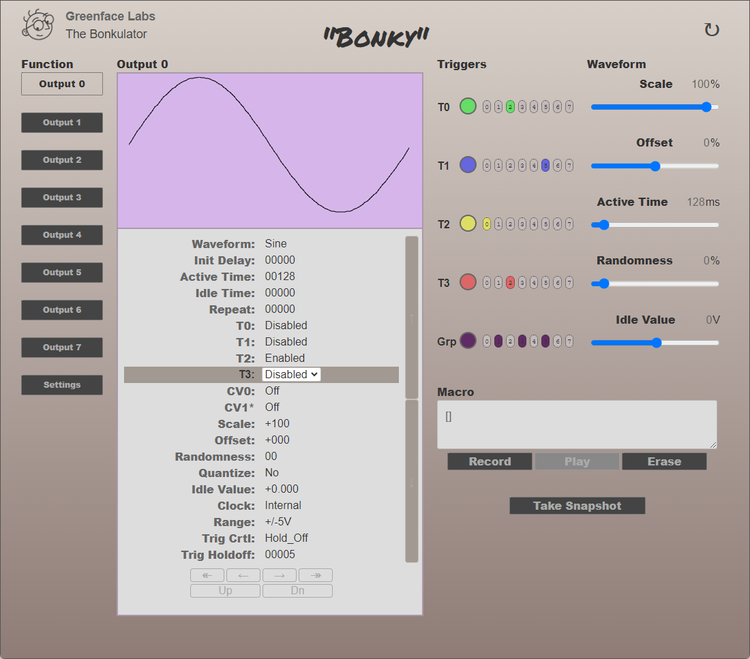
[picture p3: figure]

Figure 3 Web Interface Example

## USB Direct Mode

USB Direct Mode allows you to control the Bonkulator via USB using a desktop app that emulates the Web Interface. It also has the added benefit of being able to display trigger events as they occur rather than having to request them as in the web app. USB Direct Mode is enabled on the Bonkulator in two ways:

- In Settings
  - USB Direct Disabled
  - USB Direct Enabled
- Terminal Command
  - U0 - USB Direct Off
  - U1 - USB Direct On

Get the desktop app from the website (https://www.greenfacelabs.com/bonkulator/). Unzip the folder into a convenient location and run the executable file contained in that folder. If you’re on a Mac, you’ll need to de-quarantine the app. See the section below if you need to do this.

Once you have the app running, you should see a screen like the following:

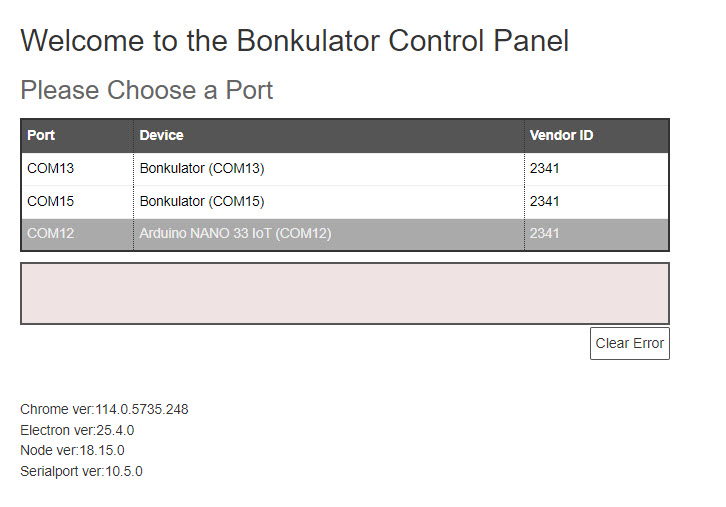
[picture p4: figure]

The control panel should recognize and enable your Bonkulators. (The Arduino Nano 33 IoT shown here goes to a Spankulator). Choose a Bonkulator by clicking on the port entry of the table. It will bring up a screen that looks like the WiFi app. Use it like you’d use the web app.

# De-quarantining on the Mac

If you download the app on the Mac and try to run it, it will say that the app is damaged and can’t be run. This is an attempt by Apple to get all apps to be distributed through their store. Until this app is available there, you’ll need to de-quarantine it to run.

To do this, using Finder navigate to the folder that contains the folder that contains the app. Select the folder that contains the app. Then click on Finder->Services->New Terminal at Folder.

This will open the Terminal. Once there issue this command:

xattr -d com.apple.quarantine bonk_cp_app.app

The app will now be ready to use.

# Drawing Waveforms

It is possible to draw your own waveforms in the Desktop and WiFi apps. Just select Settings->User Waveforms. Choose a user waveform from the dropdown menu. Then click Draw Waveform.

Use the mouse or touchpad to draw. Once you’re done, click Save Waveform. Or you may click Cancel Draw Waveform to abandon the edits.

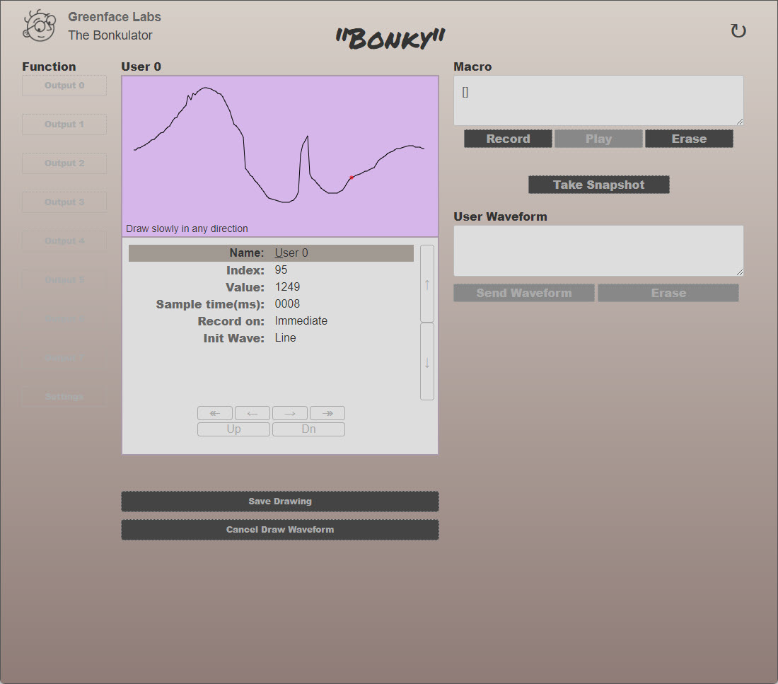
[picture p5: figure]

Figure 4 Draw Waveform Example

# Importing Waveforms

Using the Wav2Bonk app, it is possible to import waveforms from .wav file. The example below shows the Wav2Bonk app positioned over the Desktop app. The contents of the clipboard have been pasted into the User Waveform text box and the Send Waveform button has been pressed. The imported waveform is shown in the User 0 display.

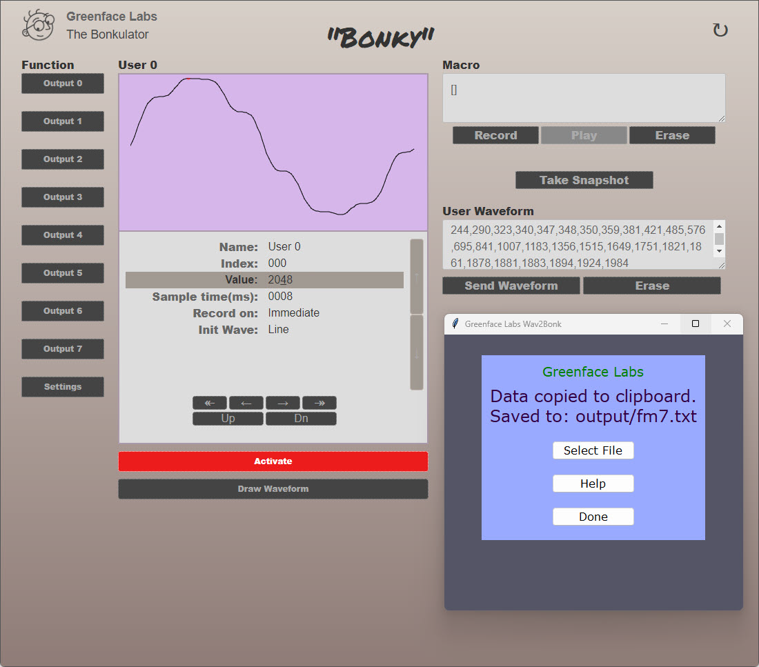
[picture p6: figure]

Figure 5 Impot Waveform Example

# Terminal Mode

Terminal mode is accessed via the MicroUSB connector on the Arduino that is on the bottom of the Bonkulator. It is always available and cannot be turned on or off.

Use a terminal emulation program like PuTTY that has VT-100 mode. The Bonkulator is set to run at 115200 baud but will adapt to the PuTTY settings.

On the Mac use this procedure:

List ports: ls /dev/tty.*

Invoke screen: screen <port> 15200

Quit screen: ctrl-a ctrl-\

#### Terminal Example Screen

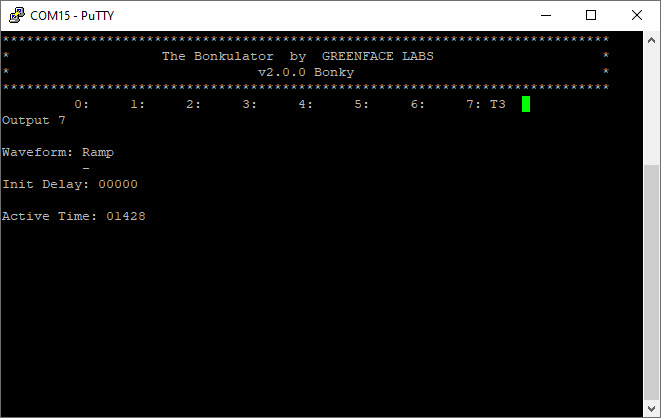
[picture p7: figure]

Figure 6 – Example Terminal Interface Screen

The Terminal screen essentially shows a copy of the user display with the addition of a product identification header that includes the software version and the unit’s name.

Below the product identification header is a status line that usually shows the state of the outputs. If an output is active, the status line will show which trigger activated that output.

Important! Only connect USB to a powered-up system. Otherwise, the 5V power from the USB will try to power the entire rack. And that’s not good. So, please disconnect the USB cable before you turn off the power.

You can get around this by using the BonkDaddy which disconnects the USB power when the Bonkulator is turned off.

#### Bonkulator Remote Commands

Command | Front Panel | Terminal | Web
Previous Parameter | ^ | [A | ^
Next Parameter | v | [B | v
Next Digit | > | [C | >
Previous Digit | < | [D | <
Increment Digit | Adjust clockwise | u | Inc
Decrement Digit | Counter-clockwise | d | Dec
Settings Function | Press & Hold ADJ | * | Settings
Disable Displays | | Z
Restore Displays | | z | Refresh Browser
Trigger Selected | | ! | Use T0-T3
Go To Function | Press Output | fx | Click Fxn Name
Select Parameter | | px | Click on Param
Select Digit# | | :xx
Enter Parameter | | xxx… | Use Param Input
Enter Parameter (alt) | | #xxx… | Use Param Input
Enter String | | $xx… | Use Param Input
Idle Value | | Vxxxx
Offset | Use Adj | Oxxxx | Use Offset slider
Scale | Use Adj | Sxxx | Use Scale slider
Randomness | Use Adj | Rxx | Use Random slider
Active Time | Use Adj | Axx | Use Active T slider
Group | N/A | Gxx | Use Group Controls
Group Active | N/A | gx | Use Grp Active Button
Set DAC | | =xxxx
Quantization Off/On | | Q0/1
Print WiFi Status | | W
Display Off/On | | J0/1
USB Direct Off/On | | U0/1
Select Trigger | | tx
Clear Trigger | | cx
Disable Selected Trig | | T0x
Enable Selected Trig | | T1x
Toggle Selected Trig | | T2x
Disable All Triggers | | T3
Trigger All Triggers | | T4
Clear All Triggers | | T5
Trigger Report | | T6
Gen Macro Selected | | M0
Gen Macro Input Cal | | M1
Gen Macro Output Cal | | M2
Gen Macro User Wave | | M1x
Dump Waveform | | Dx y
Comment (for scripts) | | /

Notes:

- Under the hood, the Web interface uses the same command characters as the Terminal
- Commands with yellow background require the user to press Enter when using a terminal. Not Required when sending via Web interface.
- Parameters and digits may be navigated in Terminal mode using the arrow keys.
- Go To Function – x means to enter a single digit in the range of 0-8. The numbers 0 – 7 denote Outputs and 8 denotes Settings.
- Select Parameter – x means a single digit in the range of 0-n, where n = the number of parameters for a chosen function minus 1.
- Enter Parameter – xxxx means up to 4 digits depending on the parameter. The range also depends on the parameter.
- Enter Parameter Alt – Start with # followed by desired number. Terminate with carriage return.
- Enter String – Start with $ followed by desired string. Terminate with carriage return.
- Disable Displays - Z is used to speed up remote scripting.
- Restore Displays – z restores display that has been disabled by command or has been turned off due to inactivity.
- Idle Value – xxxx ranges from -5478 to +5478 or 0 to 10956 depending on output range setting. This number, divided by 1000, is the actual output voltage.
- Offset – xxxx ranges from -100 to +100
- Scale – xxxx ranges from -100 to +100
- Randomness – xx ranges from 0 to 99
- Set DAC – xxxx ranges from 0 – 4095. This sets the Idle Value of the selected output.
- Group – xx ranges from 0-255. Sets bitmap indicating which outputs are grouped.
- Group Active – x ranges from 0-1. Sets whether the group is active or not.
- Display On (J1) and Display Off (J0) just affect the OLED display. Turning off the OLED display noticeably speeds up response when using the terminal interface.
- Select Trigger – x denotes trigger number (0 – 3). This command affects other trigger commands.
- Clear Trigger – x denotes Output (0-7)
- Disable/Enable/Toggle Selected Trigger – x denotes Output (0-7)
- Gen Macro – These commands are used to capture the parameter settings for scripting. See below section for more details.
- Gen Macro User Wave - x denotes wave number.
- Dump Waveform - x denotes Output (0-7). This sends the 128 values to the terminal. If y is present, it dumps the reference waveform, which is the waveform before parameters are applied (scale, offset, etc.)
- Comment – the / character causes the following text up until the carriage return to be ignored.

#### Grouping Outputs

When using the remote apps, it is possible to control several outputs with one command by grouping the outputs. The commands affected are: Offset, Scale and Randomness, Active Time, and Idle Value.

For example, the Offset slider can simultaneously control the offset parameter of several outputs. Just select which outputs you want by clicking on them.

#### Generating Parameter Macros

Software updates often contain new features that affect EEPROM allocation and thus will require initialization of the EEPROM when installed. This means that all parameters, user waveforms and calibration data will be lost and must be re-entered.

Parameter Macros are a way of minimizing the impact of this condition. Parameter Macros are created using Terminal Mode. When a Macro is created, it will be sent to the terminal screen where it can be copied and pasted into a text file for later use.

To run the Macro, merely paste it into the Terminal screen. Do this after a software update and whenever you need to set parameters to a known state. It is recommended that Calibration data macros only be run after a software update or if calibration data is lost or corrupted.

Macros are initiated by the ‘M’ character followed by a number that signifies the operation.

- M0 generates a macro that contains the parameters for the currently selected function.
- M1 generates a macro that contains the Input calibration data
- M2 generates a macro that contains the Output calibration data
- M10 – M17 generate macros that contain the User Waveform data. The selected waveform will equal the entered number – 10. I.e., M15 denotes User Waveform 5.

# Software Update

When a software update becomes available, it will be posted on the website as a zipped package. The package contains 6 files. Unzip these into an empty folder on your machine.

1. arduino-cli.exe
2. Bonkulator.ino.bin
3. Bonkulator.ino.elf
4. Release.txt
5. Update.bat
6. Blink.ino.elf.uf2 (for disaster recovery)

These files work for the Windows OS.

Follow these steps to update the code. This procedure ensures that your rack won’t be inadvertently powered by the USB +5 volt supply.

1. Note: If the update changes the EEPROM storage mapping, the unit will automatically initiate a Software Reset. Any stored settings will be lost, so make sure to save these settings before updating if they are important. See Generating Parameter Macros
2. Turn off power to the rack and remove the Bonkulator.
3. Leaving the power cable connected, place the Bonkulator on a non-conductive surface. Make sure nothing touches the Bonkulator that might cause a short.
4. Re-power the rack and plug micro-USB cable into the Bonkulator.
5. Run update.bat. It will show available COM ports. Choose by entering the number of the port.
6. If it connects properly, you will see Windows announce a new drive has been mounted. The code is copied to this drive. If the update succeeds, the Bonkulator will reboot as normal with the new software installed and the drive will be removed. You can see the new version number in the Settings function.
7. Note that an upload generates a file named: Bonkulator.ino.elf.uf2

## Disaster Recovery

When things go wrong, as they sometimes do, the Bonkulator might become unresponsive. When this happens, the program must be reset. Usually recycling the power* will fix the problem, but occasionally things have gone so bad that the code must be reloaded.

Usually, following the above update process will work. But occasionally things might have gone so bad that a hardware reset must be performed. There is a reset button on the Arduino 33 IoT. Pressing this twice quickly will force the Arduino into bootloader mode. You will see the yellow LED pulsate to indicate when the Arduino is in bootloader mode. The update process should work at this time.

If pressing the reset button doesn’t work, put a jumper onto J20 and press reset again. This should open a drive on your computer. When this happens, remove the jumper. Drag the file Blink.ino.elf.uf2 to the drive. Once loaded, you should see the Arduino blink some LEDs. The normal update process should now work.

Please contact Greenface Labs directly if this doesn’t work.

*Make sure to unplug the USB cable before removing power.

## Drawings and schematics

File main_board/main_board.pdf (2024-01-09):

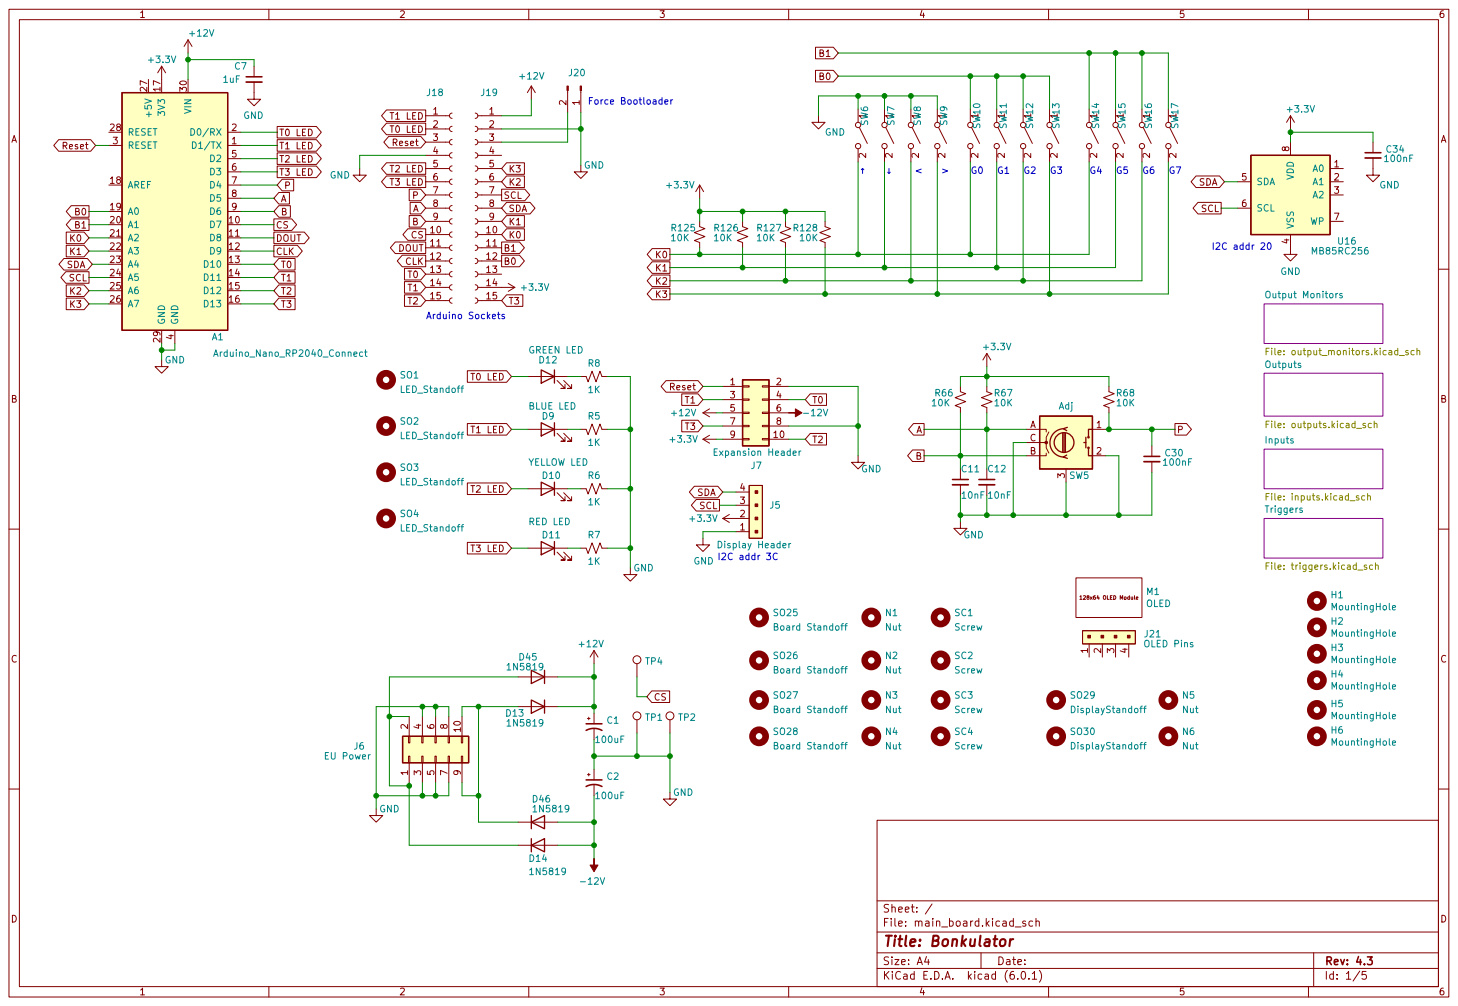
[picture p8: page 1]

1 2 SW17 SO30 DisplayStandoff N5 Nut N6 Nut N1 Nut TP2 N4 Nut N3 Nut C30

4 SDA 5 SCL 6 WP 7 VDD

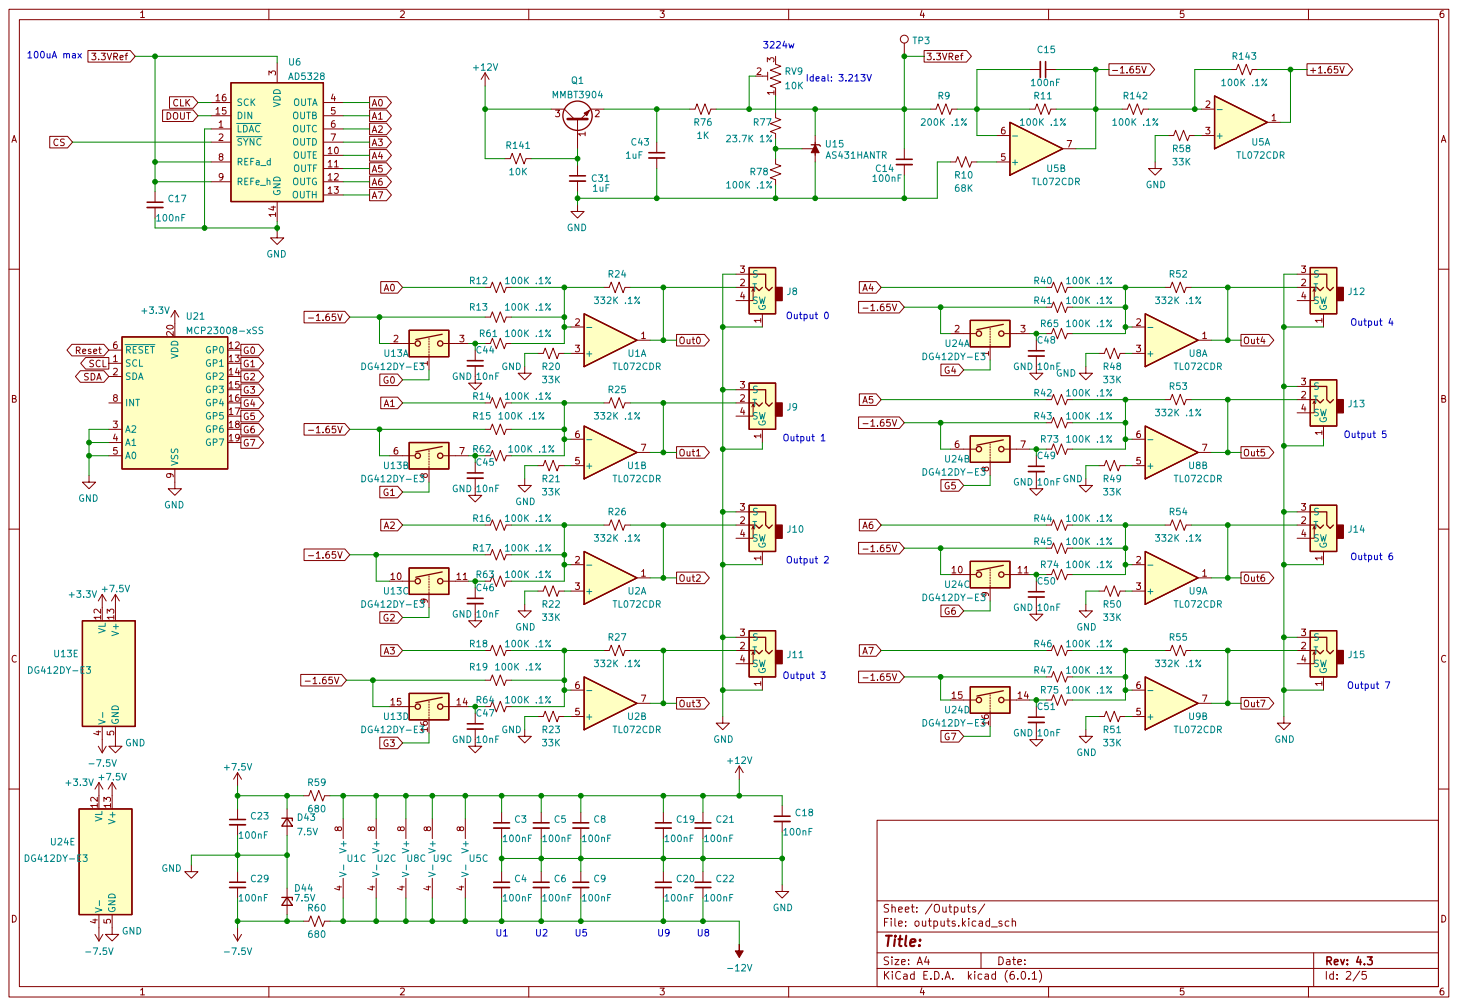
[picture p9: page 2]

3 OUTA 4 OUTB 5 OUTC 6 OUTD 7 REFa_d 8 REFe_h 9 U6AD5328 G

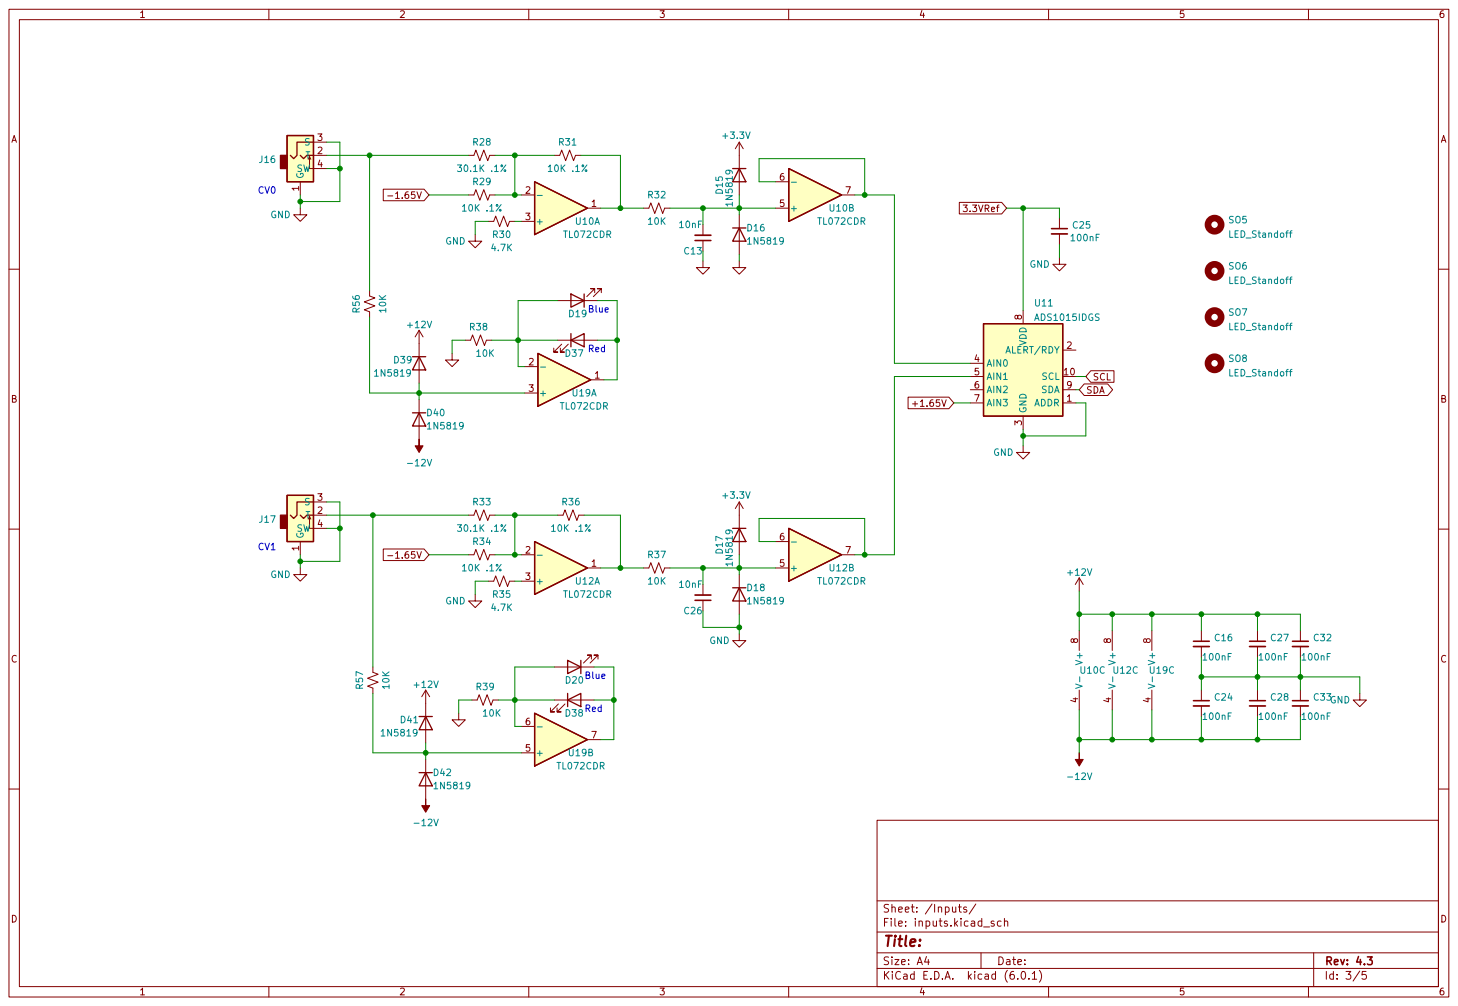
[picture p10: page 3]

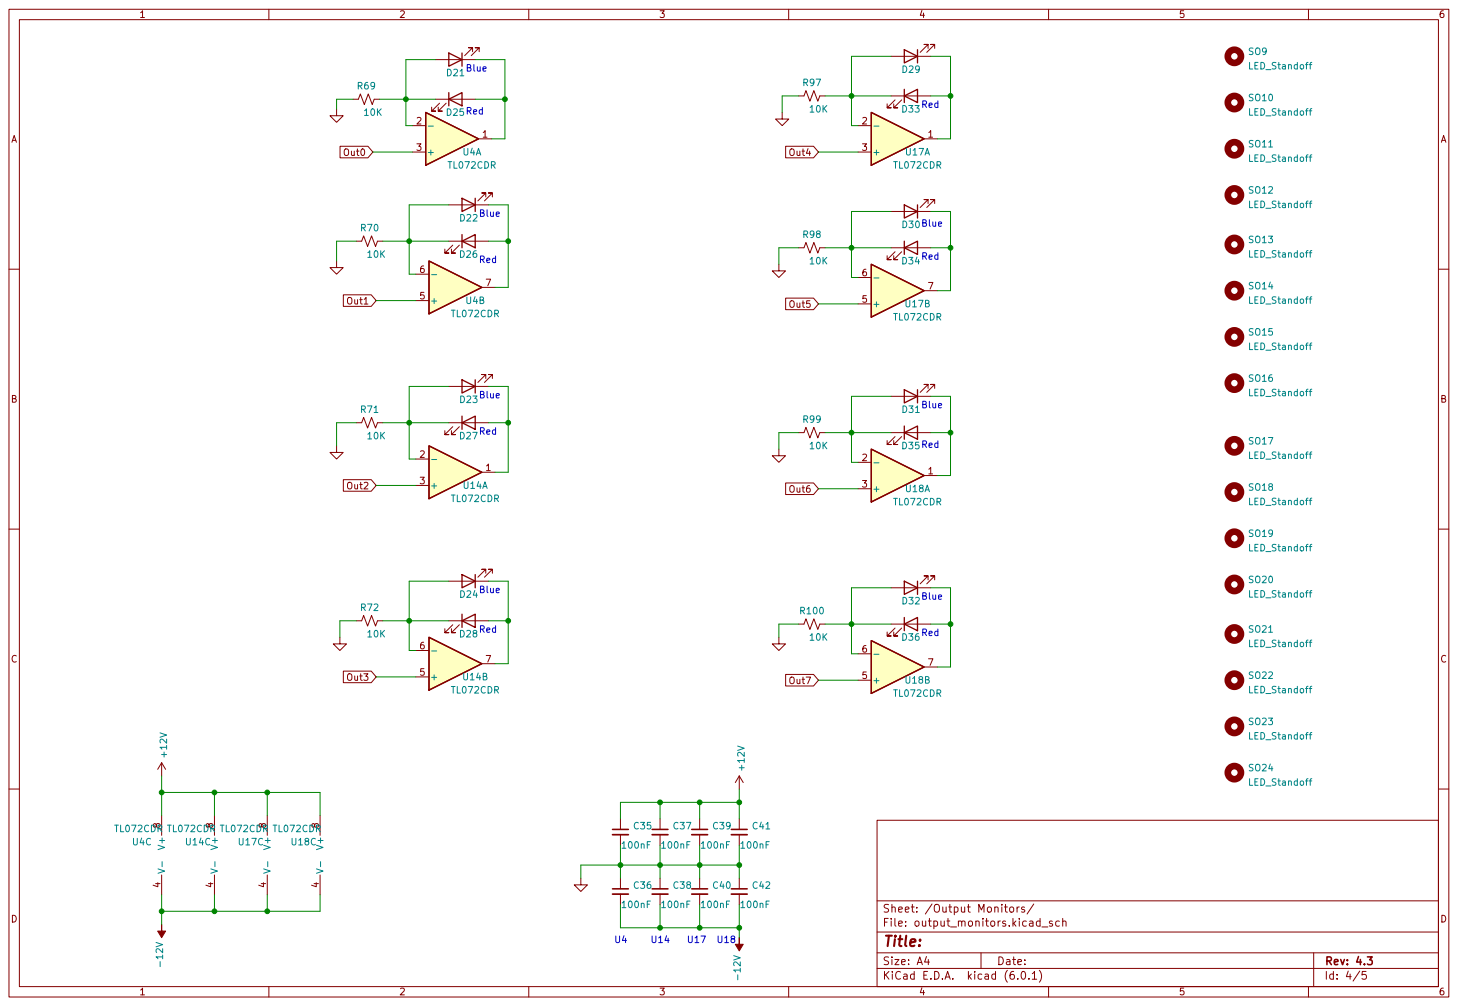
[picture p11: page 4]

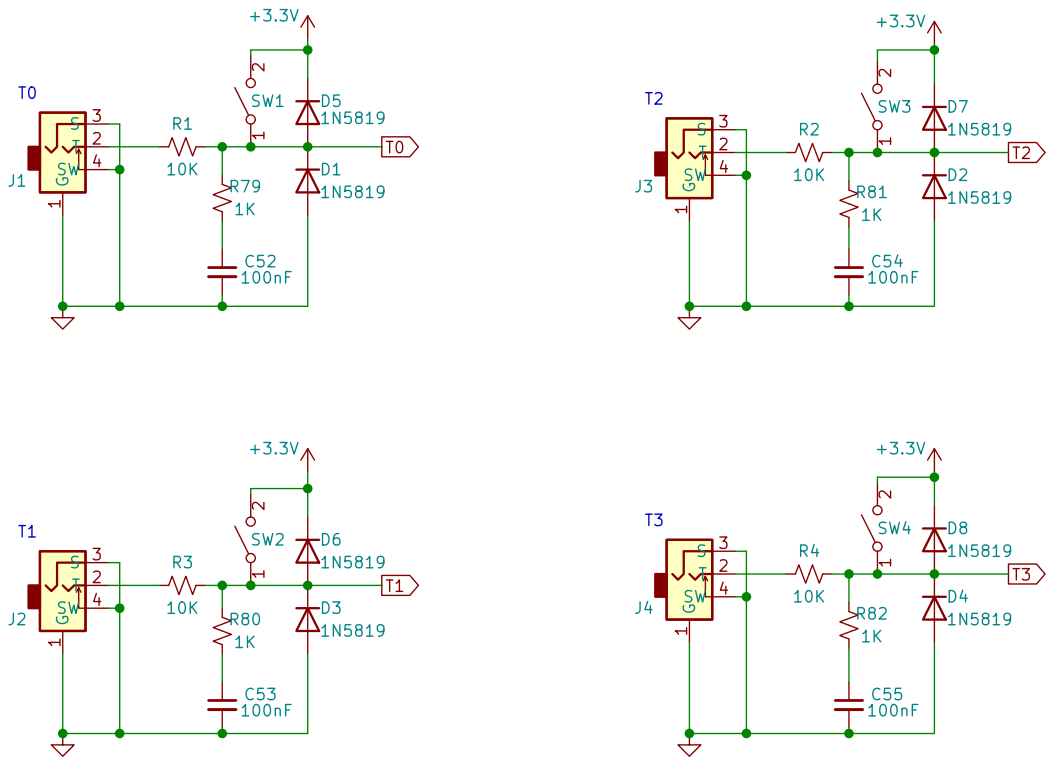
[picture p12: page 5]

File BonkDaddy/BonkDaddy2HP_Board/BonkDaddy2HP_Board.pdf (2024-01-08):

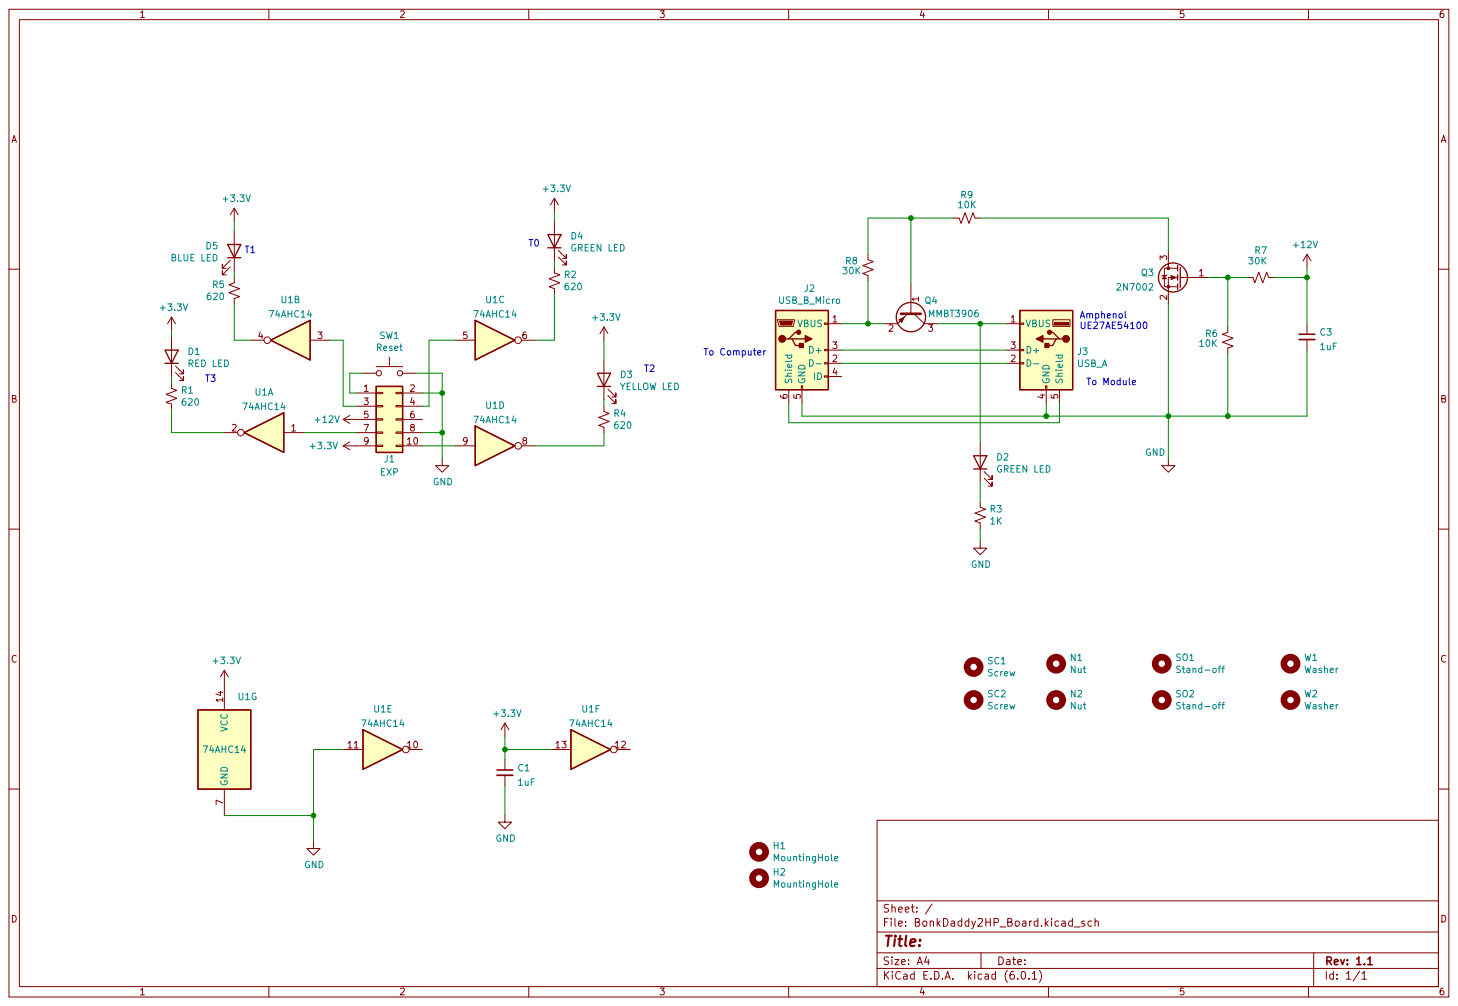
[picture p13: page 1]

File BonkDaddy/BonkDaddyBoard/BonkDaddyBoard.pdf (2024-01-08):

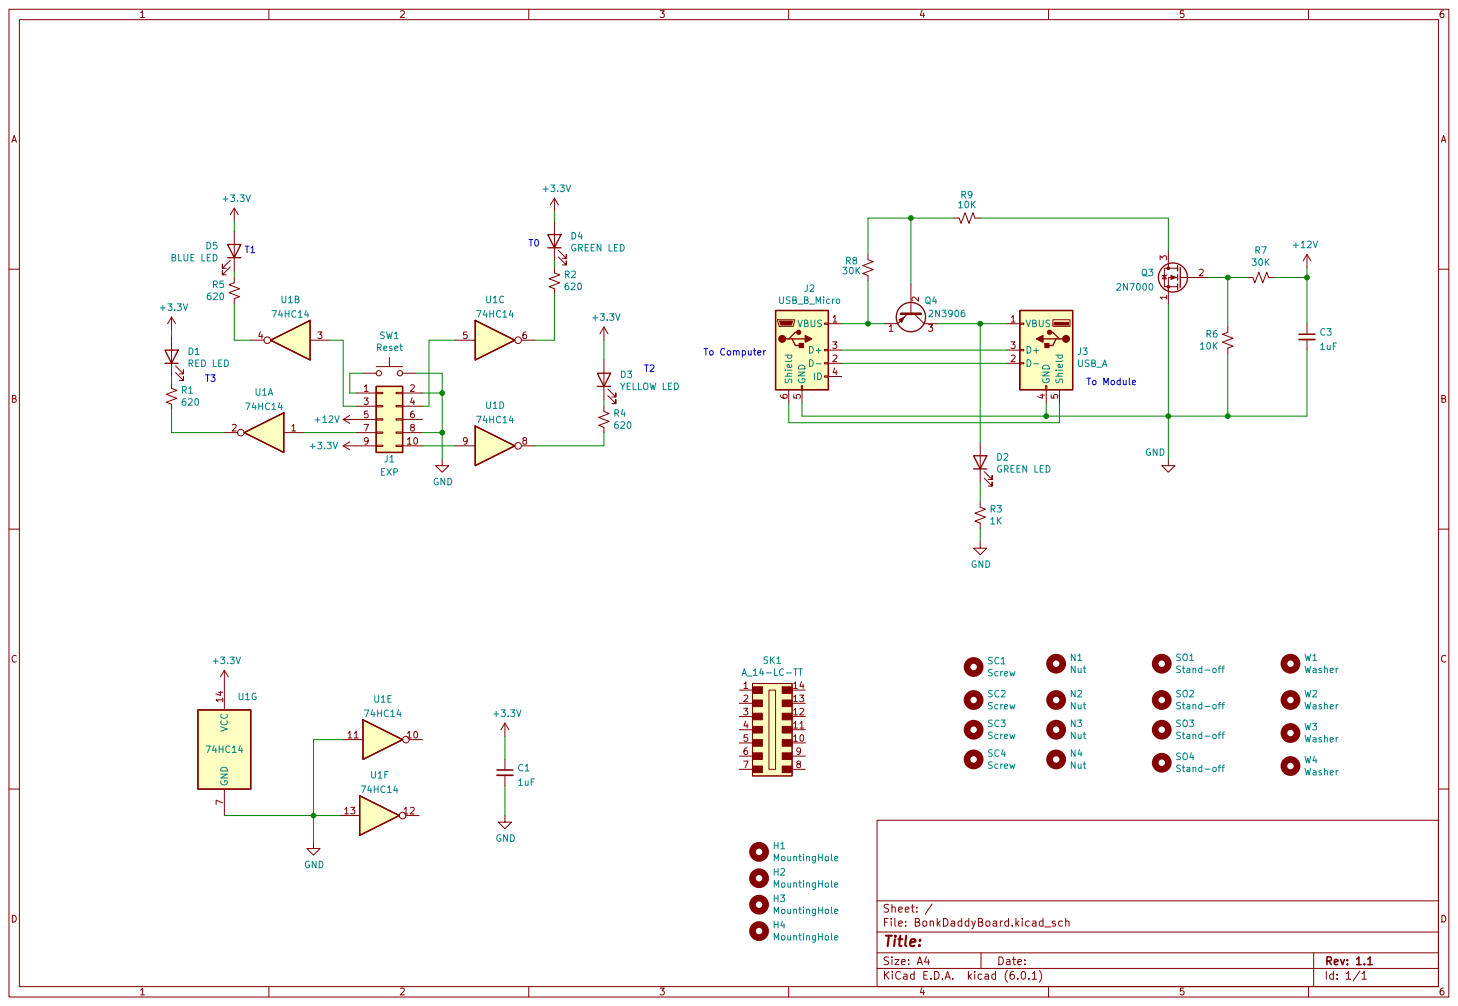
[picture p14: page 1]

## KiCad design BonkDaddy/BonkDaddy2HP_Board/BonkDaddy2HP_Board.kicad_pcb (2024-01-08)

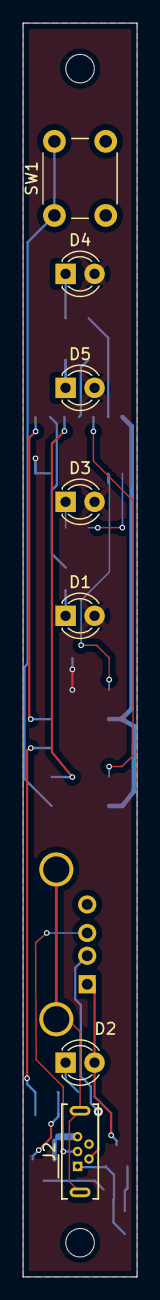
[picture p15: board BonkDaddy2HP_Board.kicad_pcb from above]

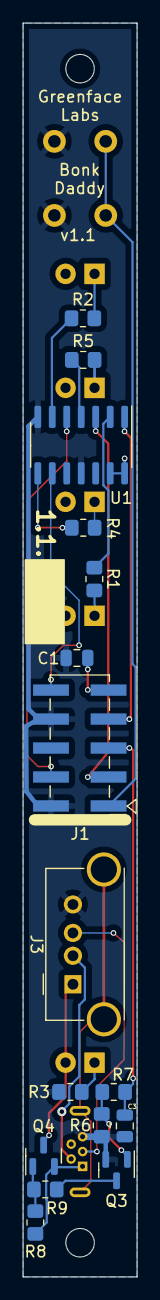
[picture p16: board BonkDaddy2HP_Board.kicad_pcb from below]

Board: 2 copper layers, 10.0 x 110.0 mm, 25 parts (16 on the bottom side), 25 nets.

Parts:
C1, C3: 1uF; C_0805_2012Metric
D1: RED LED; LED_D3.0mm
D2, D4: GREEN LED; LED_D3.0mm
D3: YELLOW LED; LED_D3.0mm
D5: BLUE LED; LED_D3.0mm
H1, H2: MountingHole; MountingHole_2.5mm
J1: EXP; PinHeader_2x05_P2.54mm_Vertical_SMD
J2: USB_B_Micro; USB_Micro-B_Wuerth_614105150721_Vertical
J3: USB_A; USB_A_Amphenol_UE27AE54100_Vertical
Q3: 2N7002; SOT-23
Q4: MMBT3906; SOT-23
R1, R2, R4, R5: 620; R_0805_2012Metric_Pad1.20x1.40mm_HandSolder
R3: 1K; R_0805_2012Metric_Pad1.20x1.40mm_HandSolder
R6, R9: 10K; R_0805_2012Metric_Pad1.20x1.40mm_HandSolder
R7, R8: 30K; R_0805_2012Metric_Pad1.20x1.40mm_HandSolder
SW1: Reset; SW_PUSH_6mm
U1: 74AHC14; SOIC-14_3.9x8.7mm_P1.27mm

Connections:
+3V3: C1.1, D1.2 (A), D3.2 (A), D4.2 (A), D5.2 (A), J1.9, U1.13, U1.14 (VCC)
+12V: C3.1, J1.5, R7.2
GND: C1.2, C3.2, J1.2, J1.8, J2.5 (GND), J3.4 (GND), Q3.2 (S), R3.1, R6.2, SW1.2, U1.7 (GND), U1.11
unnamed: D1.1 (K), R1.2
unnamed: D2.1 (K), R3.2
unnamed: D2.2 (A), J3.1 (VBUS), Q4.3 (C)
unnamed: D3.1 (K), R4.2
unnamed: D4.1 (K), R2.2
unnamed: D5.1 (K), R5.2
unnamed: J1.1, SW1.1
unnamed: J1.3, U1.3
unnamed: J1.4, U1.5
unnamed: J1.7, U1.1
unnamed: J1.10, U1.9
unnamed: J2.1 (VBUS), Q4.2 (E), R8.2
unnamed: J2.2 (D-), J3.2 (D-)
unnamed: J2.3 (D+), J3.3 (D+)
unnamed: J2.6 (Shield), J3.5 (Shield)
unnamed: Q3.1 (G), R6.1, R7.1
unnamed: Q3.3 (D), R9.1
unnamed: Q4.1 (B), R8.1, R9.2
unnamed: R1.1, U1.2
unnamed: R2.1, U1.6
unnamed: R4.1, U1.8
unnamed: R5.1, U1.4

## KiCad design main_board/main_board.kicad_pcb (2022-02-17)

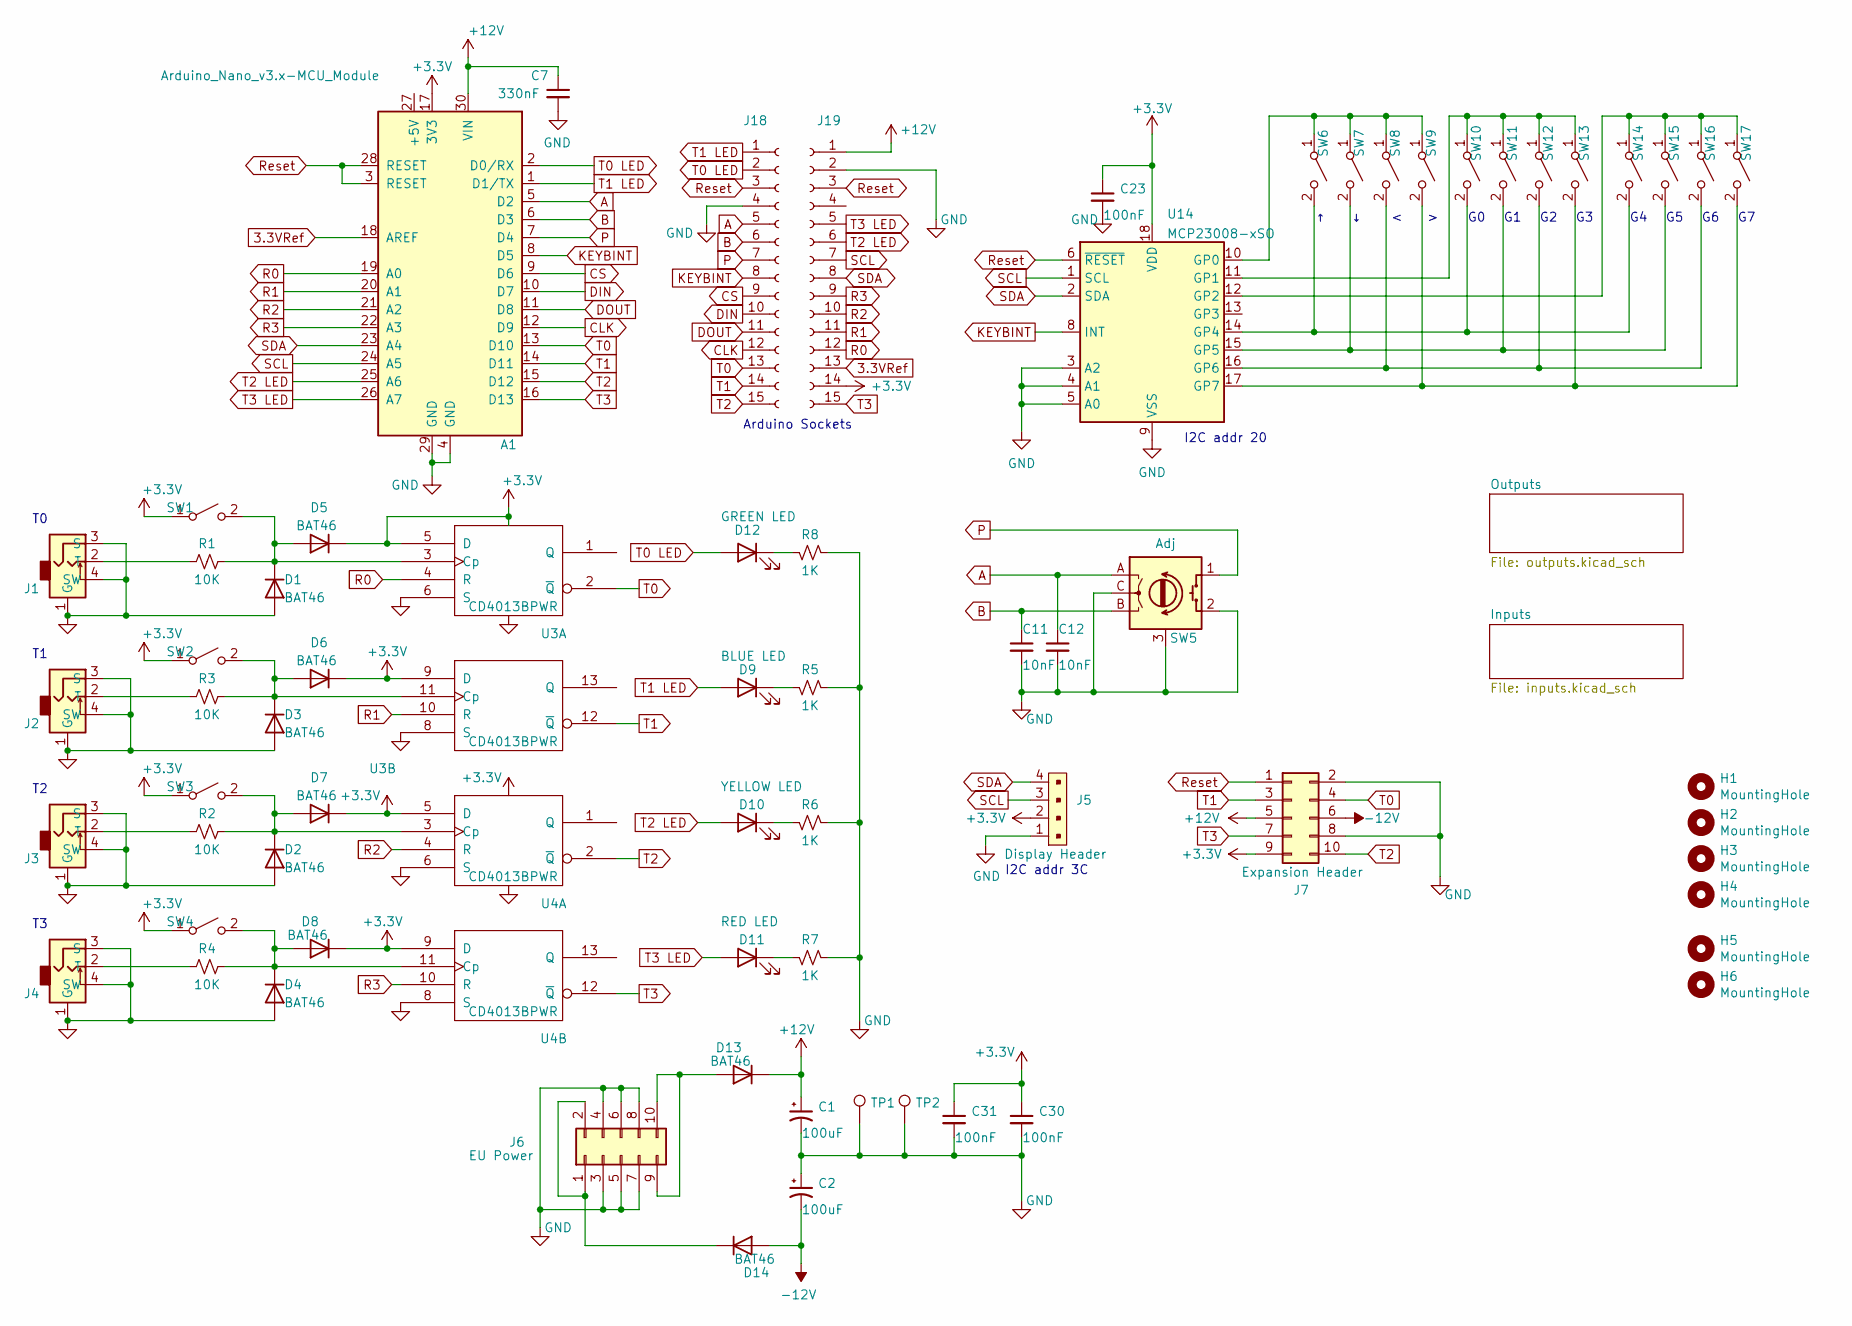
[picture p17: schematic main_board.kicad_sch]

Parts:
A1: Arduino_Nano_v3.x-MCU_Module; Arduino_Nano; Digi-Key Part 1050-ABX00053-ND
C1, C2: 100uF; CP_Elec_6.3x5.4_Nichicon; Digi-Key Part 399-EDH107M016A9GAACT-ND
C7: 330nF; C_0805_2012Metric_Pad1.18x1.45mm_HandSolder; Digi-Key Part 311-1888-1-ND
C11, C12: 10nF; C_0805_2012Metric_Pad1.18x1.45mm_HandSolder; Digi-Key Part 311-1136-1-ND
C23, C30, C31: 100nF; C_0805_2012Metric_Pad1.18x1.45mm_HandSolder; Digi-Key Part 478-10836-1-ND
D1, D2, D3, D4, D5, D6, D7, D8, D13, D14: BAT46; D_0805_2012Metric_Pad1.15x1.40mm_HandSolder; Digi-Key Part 478-7800-1-ND
D9: BLUE LED; LED_D3.0mm; Digi-Key Part 160-1035-ND
D10: YELLOW LED; LED_D3.0mm; Digi-Key Part 160-1035-ND
D11: RED LED; LED_D3.0mm; Digi-Key Part 160-1035-ND
D12: GREEN LED; LED_D3.0mm; Digi-Key Part 160-1035-ND
H1, H2, H3, H4: MountingHole; MountingHole_2.5mm
H5, H6: MountingHole; MountingHole_2.5mm-No-Margin
J1, J2, J3, J4: 3.5mm Jack; Molex-0472570001; Digi-Key Part WM17366-ND
J5: Display Header; OLED_Header_Slim; MPN 0022232041; Digi-Key Part SAM1011-04-ND
J6: EU Power; PinHeader_2x05_P2.54mm_Vertical; Digi-Key Part S2011EC-05-ND
J7: Expansion Header; PinHeader_2x05_P2.54mm_Vertical; Digi-Key Part S2011EC-05-ND
J18, J19: Conn_01x15_Female; ArduinoConnector; LCSC Part # C124408
R1, R2, R3, R4: 10K; R_0805_2012Metric_Pad1.20x1.40mm_HandSolder; Digi-Key Part 13-RC0805JR-1010KLCT-ND
R5, R6, R7, R8: 1K; R_0805_2012Metric_Pad1.20x1.40mm_HandSolder; Digi-Key Part 311-10KARCT-ND
SW1, SW2, SW3, SW4, SW6, SW7, SW8, SW9, SW10, SW11, SW12, SW13, SW14, SW15, SW16, SW17: Push Button; SW_PUSH_6mm; Digi-Key Part 450-1643-ND
SW5: Adj; Rotary_Encoder_Switched_PEC11R; Digi-Key Part 987-1187-ND
TP1, TP2: TestPoint; TestPoint_Keystone_5005-5009_Compact; Digi-Key Part 36-5006-ND
U3, U4: CD4013BPWR; TSSOP-14_4.4x5mm_P0.65mm; LCSC Part # C406860
U14: MCP23008-xSO; SOIC-18W_7.5x11.6mm_P1.27mm; Digi-Key Part MCP23008-E/SO-ND

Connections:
3.3VRef: A1.18 (AREF), J19.13; also elsewhere on the board
+3V3: A1.17 (3V3), C23.1, C30.1, C31.1, D5.1 (K), D6.1 (K), D7.1 (K), D8.1 (K), J5.2, J7.9, J19.14, SW1.1 (A), SW2.1 (A), SW3.1 (A), SW4.1 (A), U3.5 (D), U3.9 (D), U3.14 (Vdd), U4.5 (D), U4.9 (D), U4.14 (Vdd), U14.18 (VDD); also elsewhere on the board
+12V: A1.30 (VIN), C1.1, C7.1, D13.1 (K), J7.5, J19.1; also elsewhere on the board
-12V: C2.2, D14.2 (A), J7.6; also elsewhere on the board
A: A1.5 (D2), C12.1, J18.5, SW5.A
B: A1.6 (D3), C11.1, J18.6, SW5.B
CLK: A1.12 (D9), J18.12; also elsewhere on the board
CS: A1.9 (D6), J18.9; also elsewhere on the board
DIN: A1.10 (D7), J18.10; also elsewhere on the board
DOUT: A1.11 (D8), J18.11; also elsewhere on the board
GND: A1.4 (GND), A1.29 (GND), C1.2, C2.1, C7.2, C11.2, C12.2, C23.2, C30.2, C31.2, D1.2 (A), D2.2 (A), D3.2 (A), D4.2 (A), J1.1 (G), J1.3 (S), J1.4 (SW), J2.1 (G), J2.3 (S), J2.4 (SW), J3.1 (G), J3.3 (S), J3.4 (SW), J4.1 (G), J4.3 (S), J4.4 (SW), J5.1, J6.3, J6.4, J6.5, J6.6, J6.7, J6.8, J7.2, J7.8, J18.4, J19.2, R5.1, R6.1, R7.1, R8.1, SW5.2 (S2), SW5.3 (GND), SW5.C, TP1.1, TP2.1, U3.6 (S), U3.7 (Vss), U3.8 (S), U4.6 (S), U4.7 (Vss), U4.8 (S), U14.3 (A2), U14.4 (A1), U14.5 (A0), U14.9 (VSS); also elsewhere on the board
KEYBINT: A1.8 (D5), J18.8, U14.8 (INT)
unnamed: D1.1 (K), D5.2 (A), R1.1, SW1.2 (B), U3.3 (Cp)
unnamed: D2.1 (K), D7.2 (A), R2.1, SW3.2 (B), U4.3 (Cp)
unnamed: D3.1 (K), D6.2 (A), R3.1, SW2.2 (B), U3.11 (Cp)
unnamed: D4.1 (K), D8.2 (A), R4.1, SW4.2 (B), U4.11 (Cp)
unnamed: D9.1 (K), R5.2
unnamed: D10.1 (K), R6.2
unnamed: D11.1 (K), R7.2
unnamed: D12.1 (K), R8.2
unnamed: D13.2 (A), J6.9, J6.10
unnamed: D14.1 (K), J6.1, J6.2
unnamed: J1.2 (T), R1.2
unnamed: J2.2 (T), R3.2
unnamed: J3.2 (T), R2.2
unnamed: J4.2 (T), R4.2
unnamed: SW6.1 (A), SW7.1 (A), SW8.1 (A), SW9.1 (A), U14.10 (GP0)
unnamed: SW10.1 (A), SW11.1 (A), SW12.1 (A), SW13.1 (A), U14.11 (GP1)
unnamed: SW6.2 (B), SW10.2 (B), SW14.2 (B), U14.14 (GP4)
unnamed: SW7.2 (B), SW11.2 (B), SW15.2 (B), U14.15 (GP5)
unnamed: SW8.2 (B), SW12.2 (B), SW16.2 (B), U14.16 (GP6)
unnamed: SW9.2 (B), SW13.2 (B), SW17.2 (B), U14.17 (GP7)
unnamed: SW14.1 (A), SW15.1 (A), SW16.1 (A), SW17.1 (A), U14.12 (GP2)
P: A1.7 (D4), J18.7, SW5.1 (S1)
R0: A1.19 (A0), J19.12, U3.4 (R)
R1: A1.20 (A1), J19.11, U3.10 (R)
R2: A1.21 (A2), J19.10, U4.4 (R)
R3: A1.22 (A3), J19.9, U4.10 (R)
Reset: A1.3 (RESET), A1.28 (RESET), J7.1, J18.3, J19.3, U14.6 (~RESET); also elsewhere on the board
SCL: A1.24 (A5), J5.3, J19.7, U14.1 (SCL); also elsewhere on the board
SDA: A1.23 (A4), J5.4, J19.8, U14.2 (SDA); also elsewhere on the board
T0: A1.13 (D10), J7.4, J18.13, U3.2 (~Q)
T0 LED: A1.2 (D0/RX), D12.2 (A), J18.2
T1: A1.14 (D11), J7.3, J18.14, U3.12 (~Q)
T1 LED: A1.1 (D1/TX), D9.2 (A), J18.1
T2: A1.15 (D12), J7.10, J18.15, U4.2 (~Q)
T2 LED: A1.25 (A6), D10.2 (A), J19.6
T3: A1.16 (D13), J7.7, J19.15, U4.12 (~Q)
T3 LED: A1.26 (A7), D11.2 (A), J19.5

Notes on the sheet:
Arduino Sockets
I2C addr 3C
I2C addr 20

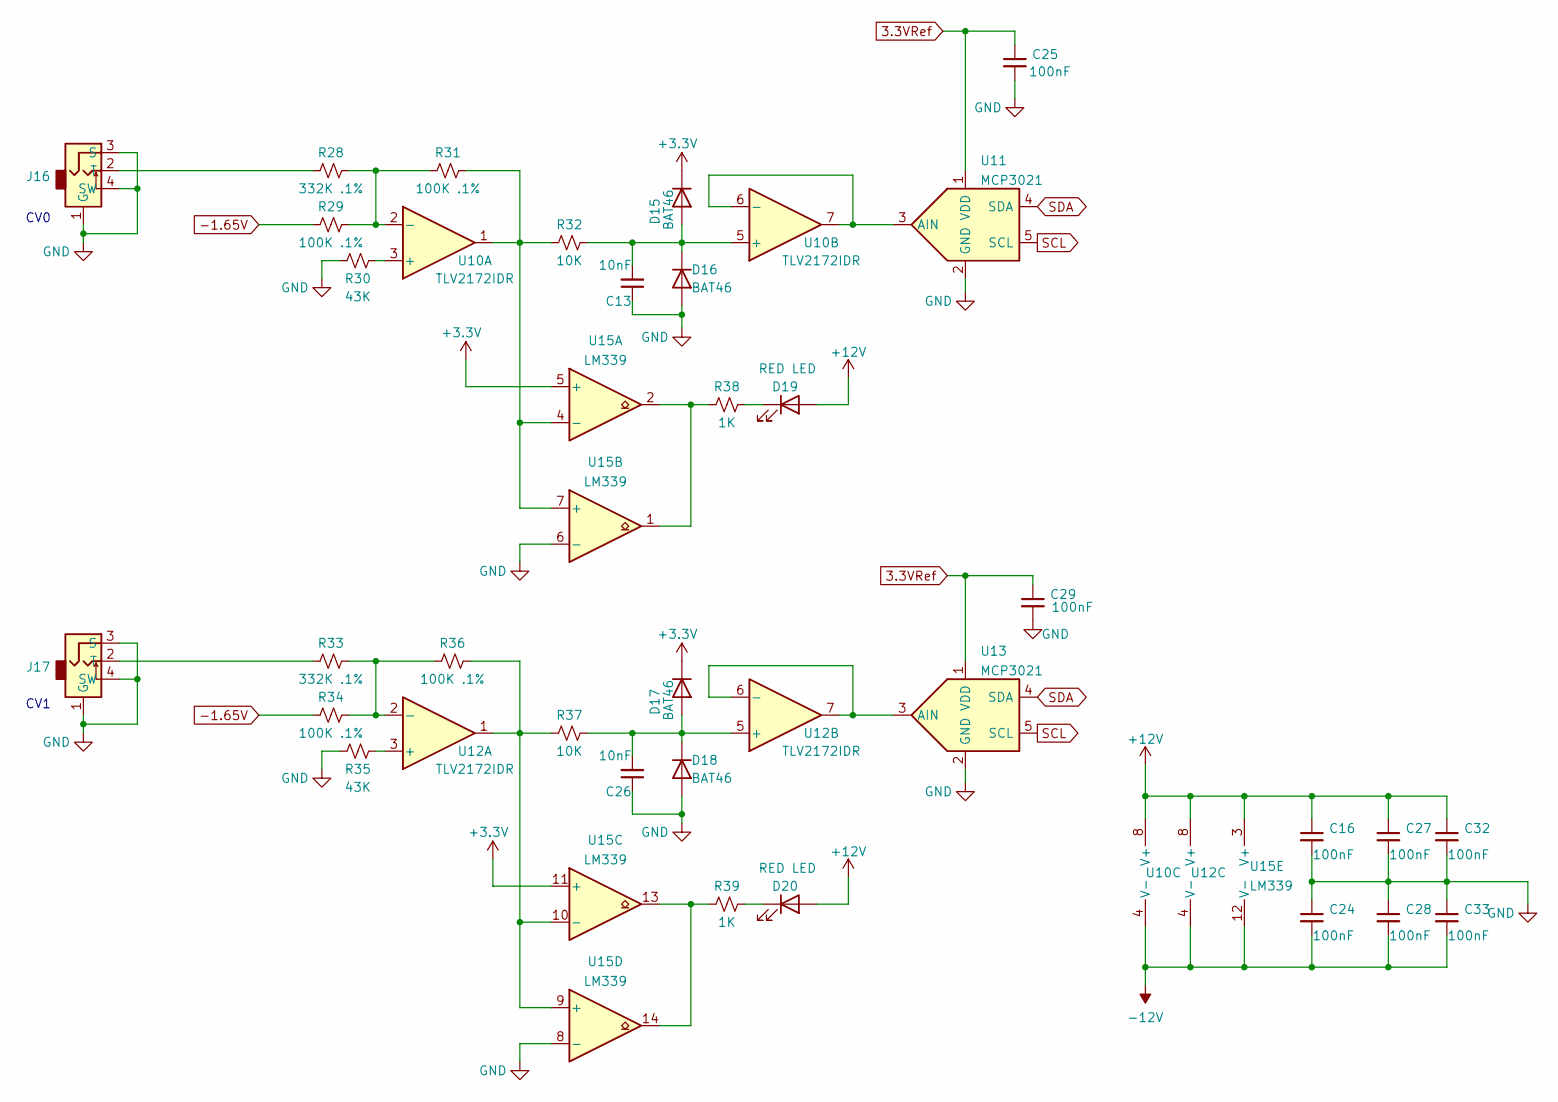
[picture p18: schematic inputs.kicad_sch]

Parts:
C13, C26: 10nF; C_0805_2012Metric_Pad1.18x1.45mm_HandSolder; Digi-Key Part 311-1136-1-ND
C16, C24, C25, C27, C28, C29, C32, C33: 100nF; C_0805_2012Metric_Pad1.18x1.45mm_HandSolder; Digi-Key Part 478-10836-1-ND
D15, D16, D17, D18: BAT46; D_0805_2012Metric_Pad1.15x1.40mm_HandSolder; Digi-Key Part 478-7800-1-ND
D19, D20: RED LED; LED_D3.0mm; Digi-Key Part 160-1035-ND
J16, J17: 3.5mm Jack; Molex-0472570001; Digi-Key Part WM17366-ND
R28, R33: 332K .1%; R_0805_2012Metric_Pad1.20x1.40mm_HandSolder; Digi-Key Part P332KDACT-ND
R29, R31, R34, R36: 100K .1%; R_0805_2012Metric_Pad1.20x1.40mm_HandSolder; Digi-Key Part YAG1759CT-ND
R30, R35: 43K; R_0805_2012Metric_Pad1.20x1.40mm_HandSolder; Digi-Key Part 311-43KARCT-ND
R32, R37: 10K; R_0805_2012Metric_Pad1.20x1.40mm_HandSolder; Digi-Key Part 13-RC0805JR-1010KLCT-ND
R38, R39: 1K; R_0805_2012Metric_Pad1.20x1.40mm_HandSolder; Digi-Key Part 311-10KARCT-ND
U10, U12: TLV2172IDR; SOIC-8-1EP_3.9x4.9mm_P1.27mm_EP2.29x3mm; Digi-Key Part 296-47385-1-ND
U11, U13: MCP3021; TSOT-23-5_HandSoldering; LCSC Part # C128576
U15: LM339; SOIC-14_3.9x8.7mm_P1.27mm; LCSC Part # C7948

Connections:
3.3VRef: C25.1, C29.1, U11.1 (VDD), U13.1 (VDD); also elsewhere on the board
+3V3: D15.1 (K), D17.1 (K), U15.5 (+), U15.11 (+); also elsewhere on the board
+12V: C16.1, C27.1, C32.1, D19.2 (A), D20.2 (A), U10.8 (V+), U12.8 (V+), U15.3 (V+); also elsewhere on the board
-1.65V: R29.2, R34.2; also elsewhere on the board
-12V: C24.2, C28.2, C33.2, U10.4 (V-), U12.4 (V-), U15.12 (V-); also elsewhere on the board
GND: C13.1, C16.2, C24.1, C25.2, C26.1, C27.2, C28.1, C29.2, C32.2, C33.1, D16.2 (A), D18.2 (A), J16.1 (G), J16.3 (S), J16.4 (SW), J17.1 (G), J17.3 (S), J17.4 (SW), R30.2, R35.2, U11.2 (GND), U13.2 (GND), U15.6 (-), U15.8 (-); also elsewhere on the board
unnamed: C13.2, D15.2 (A), D16.1 (K), R32.1, U10.5 (+)
unnamed: C26.2, D17.2 (A), D18.1 (K), R37.1, U12.5 (+)
unnamed: D19.1 (K), R38.2
unnamed: D20.1 (K), R39.2
unnamed: J16.2 (T), R28.2
unnamed: J17.2 (T), R33.2
unnamed: R28.1, R29.1, R31.2, U10.2 (-)
unnamed: R30.1, U10.3 (+)
unnamed: R31.1, R32.2, U10.1, U15.4 (-), U15.7 (+)
unnamed: R33.1, R34.1, R36.2, U12.2 (-)
unnamed: R35.1, U12.3 (+)
unnamed: R36.1, R37.2, U12.1, U15.9 (+), U15.10 (-)
unnamed: R38.1, U15.1, U15.2
unnamed: R39.1, U15.13, U15.14
unnamed: U10.6 (-), U10.7, U11.3 (AIN)
unnamed: U12.6 (-), U12.7, U13.3 (AIN)
SCL: U11.5 (SCL), U13.5 (SCL); also elsewhere on the board
SDA: U11.4 (SDA), U13.4 (SDA); also elsewhere on the board

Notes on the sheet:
CV0
CV1

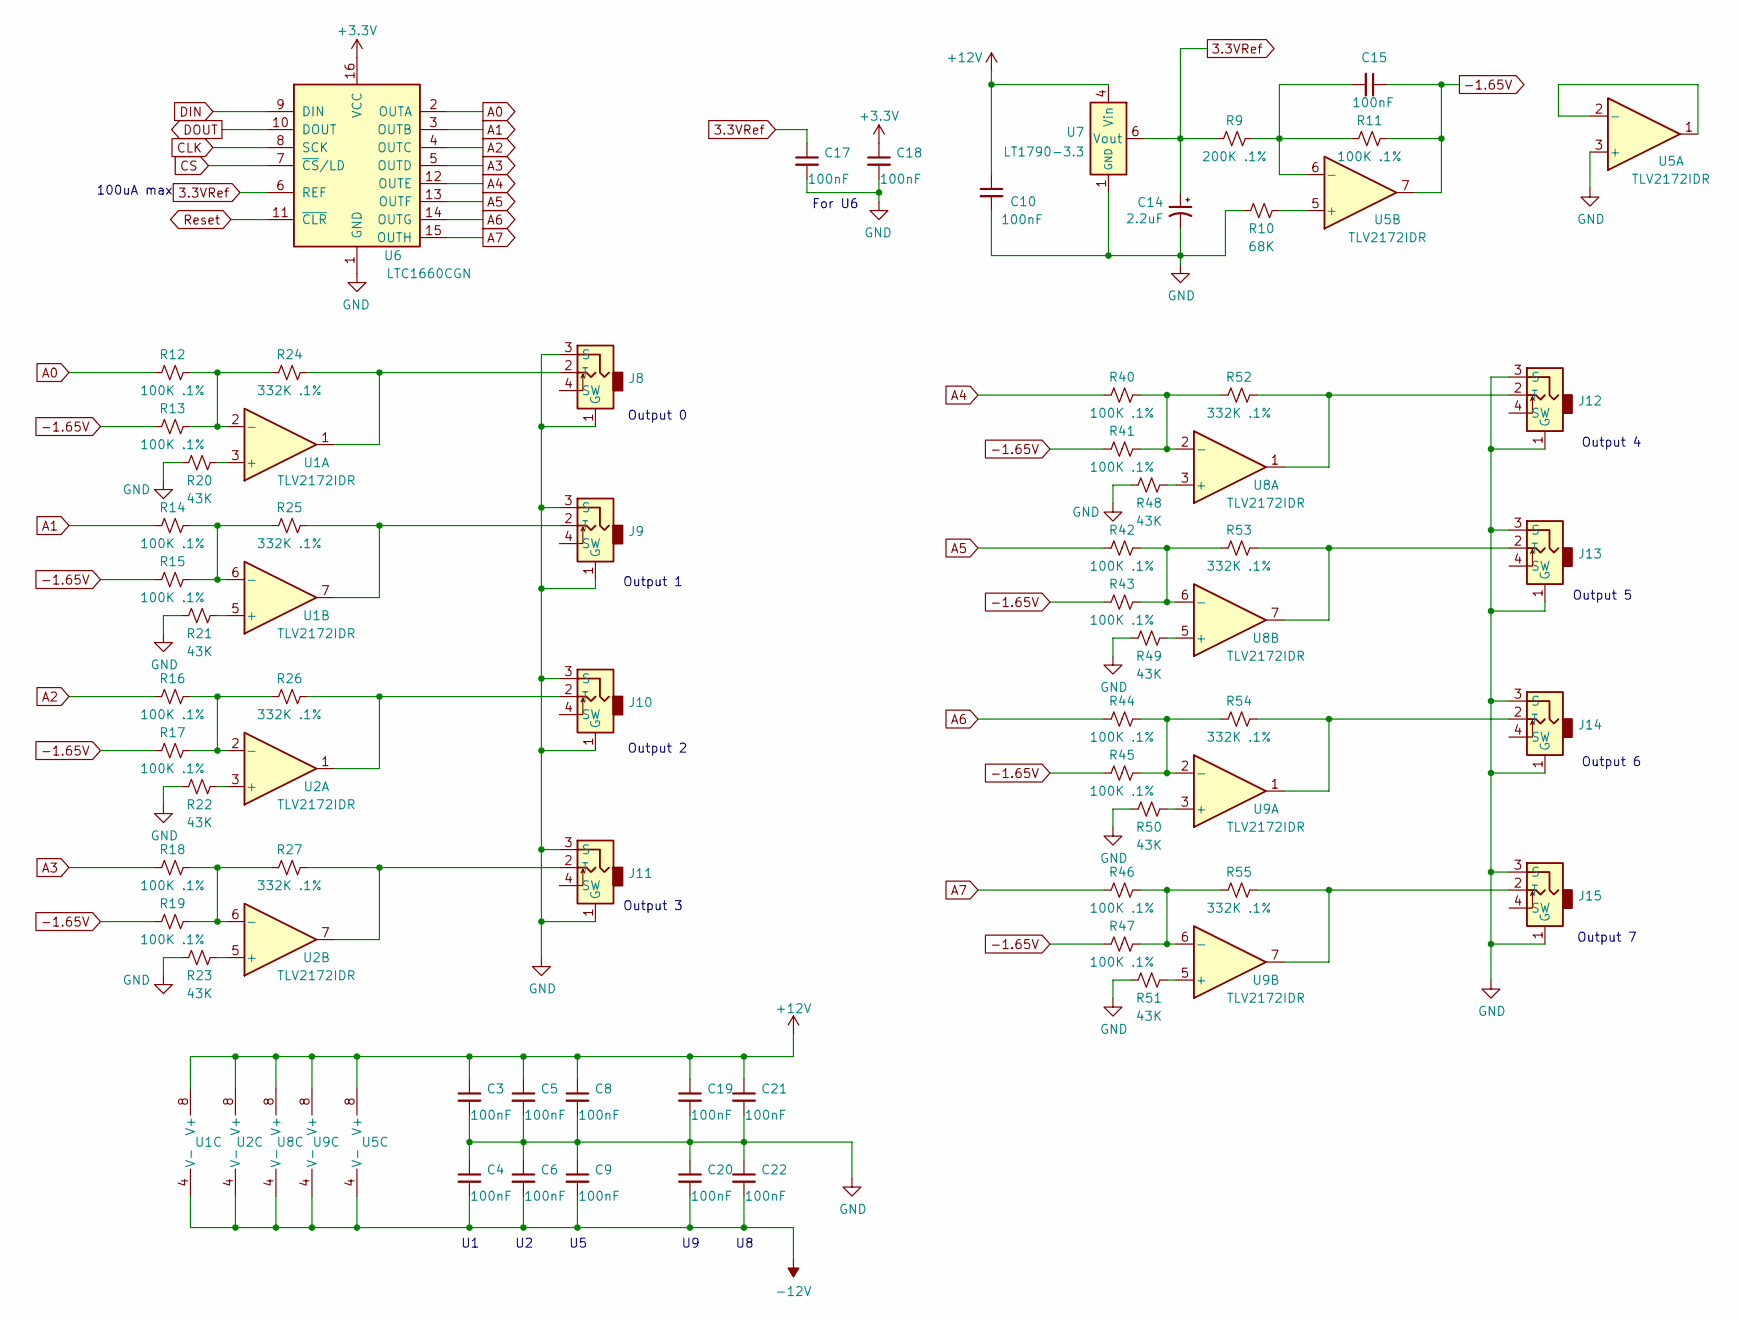
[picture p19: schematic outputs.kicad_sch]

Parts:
C3, C4, C5, C6, C8, C9, C10, C15, C17, C18, C19, C20, C21, C22: 100nF; C_0805_2012Metric_Pad1.18x1.45mm_HandSolder; Digi-Key Part 478-10836-1-ND
C14: 2.2uF; CP_EIA-2012-15_AVX-P; Digi-Key Part 478-3262-1-ND
J8, J9, J10, J11, J12, J13, J14, J15: 3.5mm Jack; Molex-0472570001; Digi-Key Part WM17366-ND
R9: 200K .1%; R_0805_2012Metric_Pad1.20x1.40mm_HandSolder; Digi-Key Part P200KDACT-ND
R10: 68K; R_0805_2012Metric_Pad1.20x1.40mm_HandSolder; Digi-Key Part 311-68KARCT-ND
R11, R12, R13, R14, R15, R16, R17, R18, R19, R40, R41, R42, R43, R44, R45, R46, R47: 100K .1%; R_0805_2012Metric_Pad1.20x1.40mm_HandSolder; Digi-Key Part YAG1759CT-ND
R20, R21, R22, R23, R48, R49, R50, R51: 43K; R_0805_2012Metric_Pad1.20x1.40mm_HandSolder; Digi-Key Part 311-43KARCT-ND
R24, R25, R26, R27, R52, R53, R54, R55: 332K .1%; R_0805_2012Metric_Pad1.20x1.40mm_HandSolder; Digi-Key Part P332KDACT-ND
U1, U2, U5, U8, U9: TLV2172IDR; SOIC-8-1EP_3.9x4.9mm_P1.27mm_EP2.29x3mm; Digi-Key Part 296-47385-1-ND
U6: LTC1660CGN; TSSOP-16-1EP_4.4x5mm_P0.65mm; Digi-Key Part LTC1660CGN#TRPBFCT-ND
U7: LT1790-3.3; TSOT-23-6; Digi-Key Part LT1790ACS6-3.3#TRMPBFCT-ND

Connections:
3.3VRef: C14.1, C17.1, R9.2, U6.6 (REF), U7.6 (Vout); also elsewhere on the board
+3V3: C18.1, U6.16 (VCC); also elsewhere on the board
+12V: C3.1, C5.1, C8.1, C10.1, C19.1, C21.1, U1.8 (V+), U2.8 (V+), U5.8 (V+), U7.4 (Vin), U8.8 (V+), U9.8 (V+); also elsewhere on the board
-1.65V: C15.1, R11.1, R13.2, R15.2, R17.2, R19.2, R41.2, R43.2, R45.2, R47.2, U5.7; also elsewhere on the board
-12V: C4.2, C6.2, C9.2, C20.2, C22.2, U1.4 (V-), U2.4 (V-), U5.4 (V-), U8.4 (V-), U9.4 (V-); also elsewhere on the board
A0: R12.2, U6.2 (OUTA)
A1: R14.2, U6.3 (OUTB)
A2: R16.2, U6.4 (OUTC)
A3: R18.2, U6.5 (OUTD)
A4: R40.2, U6.12 (OUTE)
A5: R42.2, U6.13 (OUTF)
A6: R44.2, U6.14 (OUTG)
A7: R46.2, U6.15 (OUTH)
CLK: U6.8 (SCK); also elsewhere on the board
CS: U6.7 (~CS/LD); also elsewhere on the board
DIN: U6.9 (DIN); also elsewhere on the board
DOUT: U6.10 (DOUT); also elsewhere on the board
GND: C3.2, C4.1, C5.2, C6.1, C8.2, C9.1, C10.2, C14.2, C17.2, C18.2, C19.2, C20.1, C21.2, C22.1, J8.1 (G), J8.3 (S), J9.1 (G), J9.3 (S), J10.1 (G), J10.3 (S), J11.1 (G), J11.3 (S), J12.1 (G), J12.3 (S), J13.1 (G), J13.3 (S), J14.1 (G), J14.3 (S), J15.1 (G), J15.3 (S), R10.2, R20.2, R21.2, R22.2, R23.2, R48.2, R49.2, R50.2, R51.2, U5.3 (+), U6.1 (GND), U7.1 (GND), U7.2 (GND); also elsewhere on the board
unnamed: C15.2, R9.1, R11.2, U5.6 (-)
unnamed: J8.2 (T), R24.1, U1.1
unnamed: J9.2 (T), R25.1, U1.7
unnamed: J10.2 (T), R26.1, U2.1
unnamed: J11.2 (T), R27.1, U2.7
unnamed: J12.2 (T), R52.1, U8.1
unnamed: J13.2 (T), R53.1, U8.7
unnamed: J14.2 (T), R54.1, U9.1
unnamed: J15.2 (T), R55.1, U9.7
unnamed: R10.1, U5.5 (+)
unnamed: R12.1, R13.1, R24.2, U1.2 (-)
unnamed: R14.1, R15.1, R25.2, U1.6 (-)
unnamed: R16.1, R17.1, R26.2, U2.2 (-)
unnamed: R18.1, R19.1, R27.2, U2.6 (-)
unnamed: R20.1, U1.3 (+)
unnamed: R21.1, U1.5 (+)
unnamed: R22.1, U2.3 (+)
unnamed: R23.1, U2.5 (+)
unnamed: R40.1, R41.1, R52.2, U8.2 (-)
unnamed: R42.1, R43.1, R53.2, U8.6 (-)
unnamed: R44.1, R45.1, R54.2, U9.2 (-)
unnamed: R46.1, R47.1, R55.2, U9.6 (-)
unnamed: R48.1, U8.3 (+)
unnamed: R49.1, U8.5 (+)
unnamed: R50.1, U9.3 (+)
unnamed: R51.1, U9.5 (+)
unnamed: U5.1, U5.2 (-)
Reset: U6.11 (~CLR); also elsewhere on the board

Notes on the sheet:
100uA max
Output 3
For U6
Output 6
Output 5
Output 1
Output 7
Output 2
Output 0
Output 4

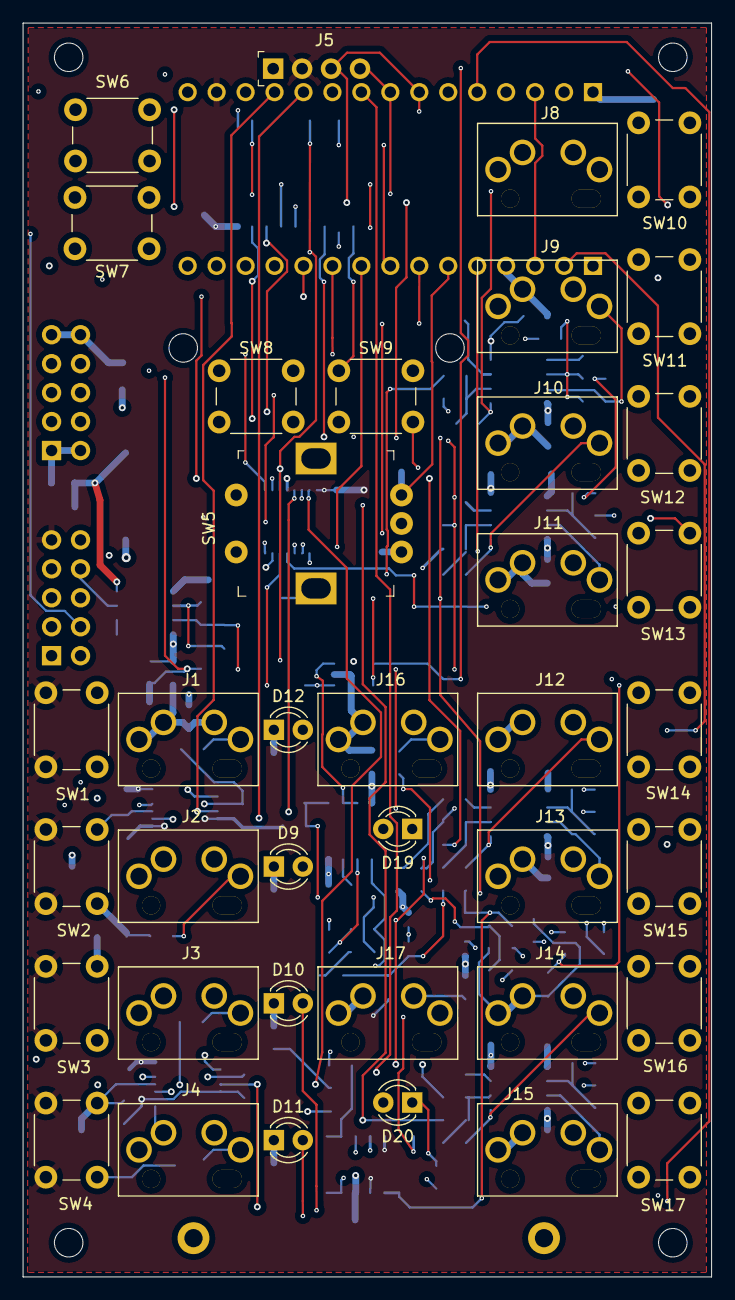
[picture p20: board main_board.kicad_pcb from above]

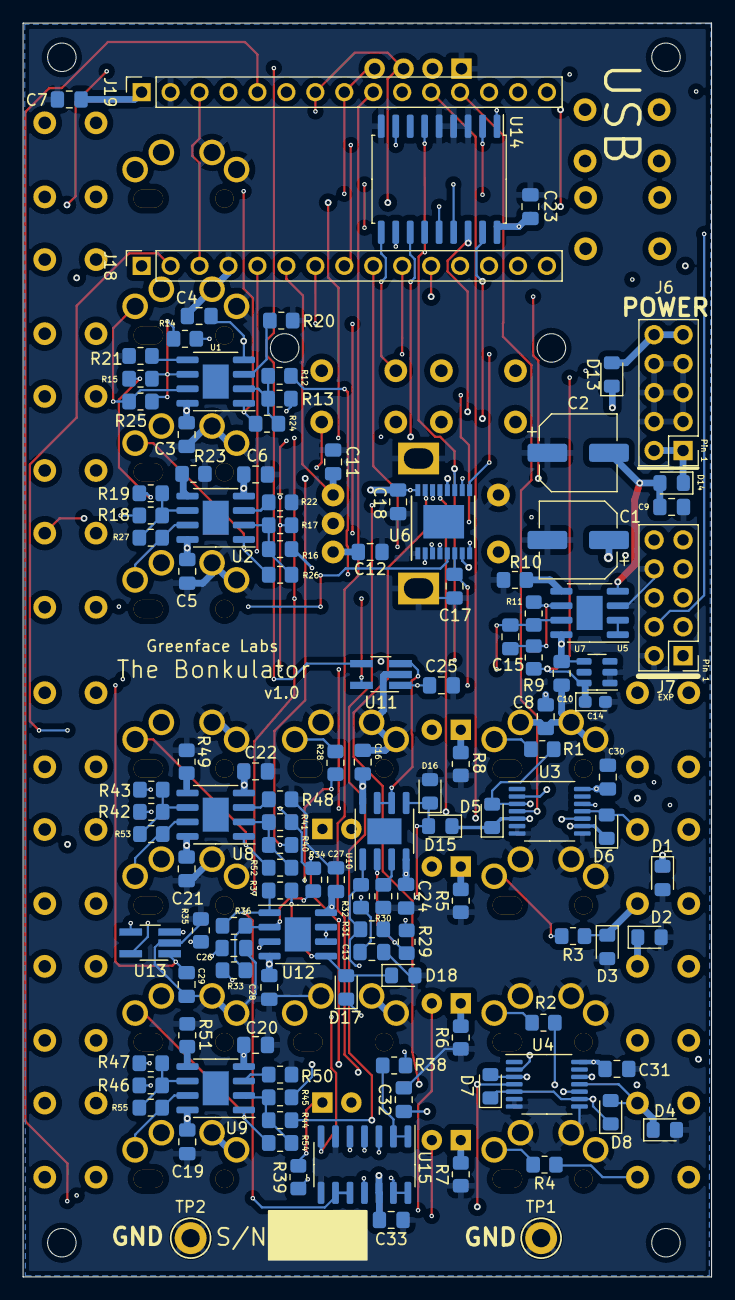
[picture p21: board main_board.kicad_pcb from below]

Board: 4 copper layers, 60.4 x 110.0 mm, 167 parts (123 on the bottom side), 101 nets.

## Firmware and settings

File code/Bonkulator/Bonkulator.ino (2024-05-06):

/*
  Bonkulator
*/

typedef void (*FunctionPointer)();
typedef void (*update_fxn)(void);

#define OUTPUT_0_FXN 0
#define OUTPUT_1_FXN 1
#define OUTPUT_2_FXN 2
#define OUTPUT_3_FXN 3
#define OUTPUT_4_FXN 4
#define OUTPUT_5_FXN 5
#define OUTPUT_6_FXN 6
#define OUTPUT_7_FXN 7
#define SETTINGS_FXN 8
#define NUM_FXNS 9

#include <Wire.h>
// Load Greenface libraries
#include "./secrets/arduino_secrets.h"
#include "version_num.h"
#include "is_release.h"
#include "face1.h" // greenface logo art

// interrupt variables
volatile uint32_t Timer0Count = 0;

// for compatibility with Spankulator in gadget code
int user_entering_param = 1;

// variables
uint16_t group = 0; // group outputs together for setting params en masse.
bool group_active = true;
String version_num = VERSION_NUM;
boolean key_held_down = false;
int16_t adc0;
int16_t adc1;
String waveform_values = "";
String system_message;
int wifi_RSSI;
boolean in_wifi();
uint16_t calculated_time_inc = 0;

// fxns defined in this file
void init_all();
void select_fxn(int fxn_index);

// settings
bool in_output_cal_fxn();
bool in_user_waveforms();
bool in_ask_init();
void ask_init();
String settings_get_device_name();
uint16_t settings_get_encoder_type();
int settings_get_inactivity_timeout();
bool wifi_enabled(void);
bool usb_direct_enabled();
void settings_put_usb_direct(int val);
void timer_service_settings();
void init_parameters();
bool settings_get_fs_fixed();
void send_data_to_USB(char cmd);
uint16_t settings_get_bounce();
String settings_get_version();

// cv fxns
void cv_set(int cv_num, int output, int16_t cv_val);
int cv_time_inc(int cv, float param);
void update_cv(int cv_num);

// timer
FunctionPointer timer_fxn;
void timer_debug();
uint16_t quantize_value(uint16_t value, uint16_t output_num);

// waveforms
void apply_params_to_waveform(int output);
uint16_t get_waveform_parts(int output);

void dump_waveform(int output_num, bool dump_ref);
void graph_waveform(int output_num);
void set_waveform(int, int);
void set_wifi_message();
int calc_wave_value(int i, int waveform, uint16_t waveform_parts);
void recv_user_waveform(String in_str);

// Output Calibration / Corrections
void output_corrections_init();
bool get_output_calibrated(int);
int get_raw_output_offset_correction(int output);
int get_output_scale_correction(int output);

// Input Calibration / Corrections
void input_corrections_init();
bool get_input_calibrated(int input);
int get_raw_input_offset_correction(int input);
int get_input_scale_correction(int input);

// triggers
bool check_any_triggers();
void clear_all_triggers();
void trigger_output(byte trig_num, int output_num);
void trigger_report();
void clear_trigger(int output_num, int trig_num);
void send_trig_status_to_USB();

// interface to modules
#include "EEPROM_fxns.h"
#include "lolevel_fxns.h"
#include "hardware_fxns.h"
#include "Rotary_Encoder_fxns.h"
#include <Greenface_gadget.h>
#include "WIFI_Util.h"

// WiFi, USB
String params_toJSON();
String list_fxns();
String output_get_fs();
String output_get_fs_offset();
String wifi_toJSON();

EEPROM_Int selected_output = EEPROM_Int(0, 7); // the output we are working on
EEPROM_Int remembered_fxn = EEPROM_Int(0, 8);  // 0-7=OutputX, 8=Settings
Greenface_gadget *selected_fxn;

#include "TRIGGER.h"

TRIGGER trig0(0);
TRIGGER trig1(1);
TRIGGER trig2(2);
TRIGGER trig3(3);
TRIGGER trig_cv0(4);
TRIGGER trig_cv1(5);
TRIGGER *selected_trigger;
#define NUM_TRIGGERS 4
TRIGGER *triggers[NUM_TRIGGERS] = {&trig0, &trig1, &trig2, &trig3};
int trigger_leds[NUM_TRIGGERS] = {T0_LED, T1_LED, T2_LED, T3_LED};
void select_trigger(int int_param); // used by Keyboard fxns

uint8_t selected_fxn_num = 0;

#include "BONK_ui.h"
#include <Greenface_wifi_fxns.h>
#include "waveform_data.h"
#include "BONK_output_fxns.h"
#include "user_waveforms_fxns.h"
#include "input_cal_fxns.h"
#include "output_cal_fxns.h"
#include "bounce_fxns.h"
#include "settings_fxns.h"
#include "hilevel_fxns.h"

#include "Keyboard_fxns.h"
#include "wifi_ui.h"

// guts of DAC servicing
#include "cv_fxns.h"
#include "timer.h"
#include "waveform_fxns.h"
#include "trigger_fxns.h"

// EEPROM_Int init_test = EEPROM_Int(0, 7); // for testing sensing changes to fram

// EEO must come after last EEPROM var is declared
#define EEO Greenface_EEPROM::eeprom_offset
void init_parameters()
{
  init_all_outputs();
  user_waveforms_init();
  settings_init();

  input_cal_init();
  output_cal_init();
  bounce_init();

  selected_output.put(0);
  remembered_fxn.put(0);

  // do this last!
  selected_output.write_int(EEPROM_INIT_FLAG, EEPROM_INIT_PATTERN);
  selected_output.write_int(EEPROM_OFFSET_FLAG, Greenface_EEPROM::eeprom_offset);
}

void init_all()
{
  input_corrections_init();
  output_corrections_init();
  init_parameters();
  wifi_init();
}

void select_fxn(int fxn_index)
{
  fxn_index = constrain(fxn_index, OUTPUT_0_FXN, SETTINGS_FXN);
  selected_fxn_num = fxn_index;
  system_message = "";
  if (fxn_index == SETTINGS_FXN)
  {
    int param_num = settings_fxn.param_num;
    selected_fxn = &settings_fxn;
    clear_all_triggers();
    settings_fxn.param_num = param_num;
    timer_fxn = &timer_service_settings;
    // outputs_begin();
  }
  else
  {
    selected_fxn = bonk_outputs[fxn_index];
    selected_output.put(fxn_index);
    timer_fxn = &timer_service_outputs;
  }
  remembered_fxn.put(fxn_index);
  selected_fxn->display();
}

// the setup function runs once when you press reset or power the board

void setup()
{
  Wire.begin();
  SPI.begin();
  Serial.begin(115200);

  // pinMode(KEYBOARD_COLUMN_0, INPUT_PULLUP);
  keyboard_begin();
  while (digitalRead(KEYBOARD_COLUMN_0) && !IS_RELEASE)
  {
  };

  ee_info.begin(false);
  ee_info.xfer();

  output_ranges_begin();

  timer_fxn = &timer_service_outputs;
  selected_output.begin(true);
  selected_output.xfer();
  remembered_fxn.begin(false);
  remembered_fxn.xfer();

  // init_test.begin(false);
  // init_test.xfer();

  // delay as bit before starting or else CRASH!!!
  delay(500);

  hardware_begin();
  timer_begin();
  // triggers_begin();
  // keyboard_begin();
  settings_begin();
  input_cal_begin();
  output_cal_begin();
  bounce_begin();
  rotary_encoder_begin();
  outputs_begin();
  user_waveforms_begin();

  ui.initDisplay();
  wifi_begin();
  if (!eeprom_is_initialized())
  {
    Serial.println(F("EEPROM is not initialized!"));
    init_all();

    // re-begin eeprom stuff
    settings_begin();
    input_cal_begin();
    output_cal_begin();
    outputs_begin();
    user_waveforms_begin();

    // selected_output.test();
  }

  outputs_begin();
  Serial.println("Howdy!");
  ui.begin(face1);
  settings_put_usb_direct(0);
  select_fxn(remembered_fxn.get());
  triggers_begin();
}

// the loop function runs over and over again forever
void loop()
{
  String status_string;
  static bool toggle = false;
  static unsigned long cnt = 0;
  bool debug = false;

  check_keyboard();
  if (debug)
    ui.terminal_debug("Keyboard checked");

  check_serial();
  if (debug)
    ui.terminal_debug("Serial checked");

  if (in_output_fxn() || in_bounce_fxn())
  {
    if (in_output_fxn())
    {
      check_triggers();
      // check_triggers();
      status_string = check_outputs();
      check_cv_inputs();
    }
    else
    {
      check_bounce_triggers();
      String temp_status_string = check_bounce();
      if (temp_status_string != "")
      {
        status_string = temp_status_string;
      }
    }
    if (debug)
      ui.terminal_debug("Outputs checked");
  }
  else if (in_user_waveform_fxn())
  {
    status_string = check_user_recording();
  }
  else if (in_input_cal_fxn())
  {
    status_string = check_input_cal();
  }
  else if (in_output_cal_fxn())
  {
    status_string = check_output_cal();
  }
  else if (in_bounce_fxn())
  {
    String temp_status_string = check_bounce();
    if (temp_status_string != "")
    {
      status_string = temp_status_string;
    }
  }

  status_string += check_wifi();

  if (debug)
    ui.terminal_debug("Server checked");

  check_rotary_encoder();
  if (debug)
    ui.terminal_debug("Encoder checked");

  if (!in_settings())
  {
    // terminal status interferes with entering strings
    // this is only done in settings IFAIK
    terminal_print_status(status_string);
  }

  ui.check_inactivity_timer(settings_get_inactivity_timeout());
  if (debug)
    ui.terminal_debug("Inactivity checked");

  if (cnt++ > 1)
  {
    toggle = !toggle;
    int val = toggle ? 200 : 255;
    analogWrite(LEDG, val);
    cnt = 0;
  }
  if (debug)
    ui.terminal_debug("Count checked");
}

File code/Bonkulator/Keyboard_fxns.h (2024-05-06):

#include <Wire.h>
// Keyboard functions

void select_button_down(void);
void scan_keyboard(void);

// #define KEYBOARD_ROW_0 0
#define KEYBOARD_ROW_1 A0
#define KEYBOARD_ROW_2 A1

#define SELECT_BUTTON_PIN 4

#define KEYBOARD_COLUMN_0 A2
#define KEYBOARD_COLUMN_1 A3
#define KEYBOARD_COLUMN_2 A6
#define KEYBOARD_COLUMN_3 A7

//
// "class" vars
volatile int keypress = 0; // set by several sources
volatile unsigned long select_button_down_time = 0;
volatile boolean select_button_pushed;
volatile uint8_t keys_row_0;
volatile uint8_t keys_row_1;
volatile uint8_t keys_row_2;

boolean esc_mode = false;
boolean select_button_available;

void reset_keyboard()
{
	// set the rows LOW so that any keypress will trigger interrupt
	// Row 0 is wired high
	digitalWrite(KEYBOARD_ROW_1, LOW);
	digitalWrite(KEYBOARD_ROW_2, LOW);
	keys_row_0 = 0;
	keys_row_1 = 0;
	keys_row_2 = 0;
	esc_mode = false;
	keypress = 0;
	select_button_pushed = false;
	select_button_available = false;
	key_held_down = false;
}

uint8_t crunch_key()
{
	uint8_t keys_row;
	// keys_row = !digitalRead(KEYBOARD_COLUMN_0);
	keys_row = analogRead(KEYBOARD_COLUMN_0) < 100 ? 1 : 0; // crazy fix for input not going low enough
	keys_row |= !digitalRead(KEYBOARD_COLUMN_1) << 1;
	keys_row |= !digitalRead(KEYBOARD_COLUMN_2) << 2;
	keys_row |= !digitalRead(KEYBOARD_COLUMN_3) << 3;
	return keys_row;
}

bool key_available()
{
	return (select_button_available) || keys_row_0 || keys_row_1 || keys_row_2;
}

void wait_all_keys_up()
{
	unsigned long started = millis();
	key_held_down = false;
	while (key_available() && millis() < started + 2000)
	{
		delay(10);
		scan_keyboard();
	}
	key_held_down = millis() >= started + 2000;
}

void scan_keyboard()
{
	uint8_t same_cnt = 0;
	uint8_t sanity_cnt = 0;
	int last_val = 0;
	int current_val;
	while (sanity_cnt++ < 100 && same_cnt < 5)
	{
		// go row by row
		digitalWrite(KEYBOARD_ROW_1, HIGH);
		digitalWrite(KEYBOARD_ROW_2, HIGH);
		keys_row_0 = crunch_key();

		// digitalWrite(KEYBOARD_ROW_0, HIGH);
		digitalWrite(KEYBOARD_ROW_1, LOW);
		digitalWrite(KEYBOARD_ROW_2, HIGH);
		delay(1);
		keys_row_1 = crunch_key();

		// digitalWrite(KEYBOARD_ROW_0, HIGH);
		digitalWrite(KEYBOARD_ROW_1, HIGH);
		digitalWrite(KEYBOARD_ROW_2, LOW);
		delay(1);
		keys_row_2 = crunch_key();

		current_val = keys_row_0 << 8 | keys_row_1 << 4 | keys_row_2;
		if (current_val == last_val)
		{
			// hooray
			same_cnt++;
		}
		else
		{
			same_cnt = 0;
		}
		last_val = current_val;
		// delay(20);
	}
	// now check rotary push button
	unsigned long now = millis();
	if (select_button_pushed)
	{
		bool being_held = !digitalRead(SELECT_BUTTON_PIN);
		if (being_held)
		{
			if (now > select_button_down_time + 2000)
			{
				keypress = '*';
				select_button_available = true;
				select_button_pushed = false;
			}
		}
		else
		{
			keypress = '!';
			select_button_available = true;
			select_button_pushed = false;
		}
	}
	else
	{
		select_button_available = false;
	}
	if (key_available() && !ui.display_is_on)
	{
		restore_display();
		wait_all_keys_up();
		reset_keyboard();
	}
	// Serial.println("Sanity: " + String(sanity_cnt));
}

void calc_keypress()
{
	esc_mode = false;
	if (keys_row_0 == 1)
	{
		esc_mode = true;
		keypress = 'A'; // up 65
		return;
	}
	if (keys_row_0 == 2)
	{
		esc_mode = true;
		keypress = 'B'; // down
		return;
	}
	if (keys_row_0 == 4)
	{
		esc_mode = true;
		keypress = 'D'; // left
		return;
	}
	if (keys_row_0 == 8)
	{
		esc_mode = true;
		keypress = 'C'; // right
		return;
	}

	if (keys_row_1 == 1)
	{
		// keypress = '0';
		select_fxn(OUTPUT_0_FXN);
		return;
	}
	if (keys_row_1 == 2)
	{
		select_fxn(OUTPUT_1_FXN);
		return;
	}
	if (keys_row_1 == 4)
	{
		select_fxn(OUTPUT_2_FXN);
		return;
	}
	if (keys_row_1 == 8)
	{
		select_fxn(OUTPUT_3_FXN);
		return;
	}

	if (keys_row_2 == 1)
	{
		select_fxn(OUTPUT_4_FXN);
		return;
	}
	if (keys_row_2 == 2)
	{
		select_fxn(OUTPUT_5_FXN);
		return;
	}
	if (keys_row_2 == 4)
	{
		select_fxn(OUTPUT_6_FXN);
		return;
	}
	if (keys_row_2 == 8)
	{
		select_fxn(OUTPUT_7_FXN);
		return;
	}
}
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

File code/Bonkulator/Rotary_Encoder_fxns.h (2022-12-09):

// Rotary Encoder
// see https://playground.arduino.cc/Main/RotaryEncoders

#define encoder0PinA ROTARY_A_PIN
#define encoder0PinB ROTARY_B_PIN

volatile int encoder0Pos = 0;
volatile unsigned long encodeTime;
int oldPosition = 0;
uint8_t wait_time = 102;

void doEncoderA()
{
  if (millis() > encodeTime + wait_time)
  {
    // look for a low-to-high on channel A
    if (digitalRead(encoder0PinA) == HIGH)
    {

      // check channel B to see which way encoder is turning
      if (digitalRead(encoder0PinB) == LOW)
      {
        encoder0Pos += 1; // CW
      }
      else
      {
        encoder0Pos += -1; // CCW
      }
    }

    else // must be a high-to-low edge on channel A
    {
      // check channel B to see which way encoder is turning
      if (digitalRead(encoder0PinB) == HIGH)
      {
        encoder0Pos += 1; // CW
      }
      else
      {
        encoder0Pos += -1; // CCW
      }
    }
    encodeTime = millis();
    // Serial.println(encoder0Pos, DEC);
    // use for debugging - remember to comment out
  }
}

void doEncoderB()
{
  if (millis() > encodeTime + wait_time)
  {
    // look for a low-to-high on channel B
    if (digitalRead(encoder0PinB) == HIGH)
    {

      // check channel A to see which way encoder is turning
      if (digitalRead(encoder0PinA) == HIGH)
      {
        encoder0Pos += 1; // CW
      }
      else
      {
        encoder0Pos += -1; // CCW
      }
    }

    // Look for a high-to-low on channel B
    else
    {
      // check channel B to see which way encoder is turning
      if (digitalRead(encoder0PinA) == LOW)
      {
        encoder0Pos += 1; // CW
      }
      else
      {
        encoder0Pos += -1; // CCW
      }
    }
    encodeTime = millis();
  }
}

void set_encoder()
{
  if (settings_get_encoder_type())
  {
    attachInterrupt(ROTARY_B_PIN, doEncoderA, CHANGE);
    attachInterrupt(ROTARY_A_PIN, doEncoderB, CHANGE);
  }
  else
  {
    attachInterrupt(ROTARY_A_PIN, doEncoderA, CHANGE);
    attachInterrupt(ROTARY_B_PIN, doEncoderB, CHANGE);
  }
}

bool encoder_is_adjusting()
{
  bool adjusting = encoder0Pos != oldPosition;
  if (adjusting)
  {
    oldPosition = encoder0Pos;
  }
  return adjusting;
}

void resetEncoder()
{
  oldPosition = encoder0Pos = 0;
}

int getEncoderValue()
{
  return (encoder0Pos > 0) ? 1 : -1;
}

void rotary_encoder_begin()
{
  resetEncoder();
  set_encoder(); // sets msb,lsb for two types of encoder
}

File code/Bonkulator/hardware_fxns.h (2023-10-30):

#include "hardware_defs.h"
#include <Greenface_AD5328.h>
#include <MCP3X21.h>
#include <Adafruit_ADS1X15.h>
#include <Adafruit_MCP23X08.h>
#include "EEPROM_ArrInt.h"

#define IN_FS_VOLTS 4.9665

// Adafruit_ADS1115 ads;  /* Use this for the 16-bit version */
Adafruit_ADS1015 ads; /* Use this for the 12-bit version */
Adafruit_MCP23X08 mcp;

Greenface_AD5328 output_device(CS_PIN, DOUT_PIN, CLK_PIN, 0);
// MCP3021 cv0_device(0x4D);
// MCP3021 cv1_device(0x53);

void hardware_begin()
{
    pinMode(DOUT_PIN, OUTPUT);
    pinMode(CLK_PIN, OUTPUT);
    pinMode(CS_PIN, OUTPUT);

    pinMode(T0_LED, OUTPUT);
    pinMode(T1_LED, OUTPUT);
    pinMode(T2_LED, OUTPUT);
    pinMode(T3_LED, OUTPUT);

    // TODO: Input pullup is broken!!!
    // https://forum.arduino.cc/t/interrupt-on-digital-pin-does-not-work-on-nano-rp2040-connect/960900/2
    // pinMode(T0_PIN, INPUT_PULLDOWN);
    // pinMode(T1_PIN, INPUT_PULLDOWN);
    // pinMode(T2_PIN, INPUT_PULLDOWN);
    // pinMode(T3_PIN, INPUT_PULLDOWN);

    analogWriteResolution(10);
    output_device.begin(AD5328_LDAC_PASSTHRU, AD5328_VDD_BOTH, AD5328_BUFFERED_BOTH, AD5328_GAIN_NONE);
    // cv0_device.init();
    // cv1_device.init();

    if (!ads.begin())
    {
        Serial.println("Failed to initialize ADS.");
        while (1)
            ;
    }
    ads.setGain(GAIN_TWO);
}

int adc_read_raw(int adc_num)
{
    int adc = 0;
    switch (adc_num)
    {
    case 0:
        adc = ads.readADC_Differential_0_3();
        break;

    case 1:
        adc = ads.readADC_Differential_1_3();
        break;

    default:
        break;
    }
    return adc;
}

int adc_read(int adc_num)
{
    int adc = adc_read_raw(adc_num) * -1;
    adc += get_raw_input_offset_correction(adc_num);
    adc *= get_input_scale_correction(adc_num) / 1000.0;
    return adc;
}

float scale_adc(int adc)
{
    return IN_FS_VOLTS * adc / 1650;
}

void dac_out(byte dac, int val)
{
    val = DAC_FS - val;
    // val = max(0, val);
    val = constrain(val, 0, DAC_FS);
    output_device.dac_out(dac, val);
    // output_device.dac_out(dac, constrain(val, 0, DAC_FS));
}

void led_debug(bool state, uint8_t led_index)
{
    switch (led_index)
    {
    case 0:
        digitalWrite(T0_LED, state);
        break;
    case 1:
        digitalWrite(T1_LED, state);
        break;
    case 2:
        digitalWrite(T2_LED, state);
        break;
    case 3:
        digitalWrite(T3_LED, state);
        break;
    }
}

void set_t0_led(bool state)
{
    digitalWrite(T0_LED, state);
}

// output range code starts here
bool output_ranges_installed = true;
typedef enum _output_range_type
{
    OUTPUT_RANGE_BIPOLAR = 0,
    OUTPUT_RANGE_UNIPOLAR = 1,
} output_range_type;

// output_range_type output_ranges[NUM_OUTPUTS] = {OUTPUT_RANGE_BIPOLAR, OUTPUT_RANGE_BIPOLAR, OUTPUT_RANGE_BIPOLAR, OUTPUT_RANGE_BIPOLAR, OUTPUT_RANGE_BIPOLAR, OUTPUT_RANGE_BIPOLAR, OUTPUT_RANGE_BIPOLAR, OUTPUT_RANGE_BIPOLAR};

void set_output_range(uint8_t output, output_range_type output_range)
{
    if (output_ranges_installed)
    {
        // output_ranges[output] = output_range;
        mcp.digitalWrite(output, output_range);
    }
}

void output_ranges_begin()
{
    if (!mcp.begin_I2C())
    {
        Serial.println("MCP not installed. ");
        output_ranges_installed = false;
        // adjust output params here?
    }
    else
    {
        for (int i = 0; i < NUM_OUTPUTS; i++)
        {
            mcp.pinMode(i, OUTPUT);
        }
    }
}

void output_ranges_init()
{
}

// for the MCP4921
// todo move this unused DAC code to a library
// void output_dac(int dac_num, int output_value)
// {
//   byte me;
//   me = (dac_num + 1) << 4 | (output_value >> 4);
//   digitalWrite(CS_PIN, LOW);
//   shiftOut(DOUT_PIN, CLK_PIN, MSBFIRST, me);
//   me = output_value << 4;
//   shiftOut(DOUT_PIN, CLK_PIN, MSBFIRST, me);
//   digitalWrite(CS_PIN, HIGH);
// }

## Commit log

2022-02-17 Init check-in
    [inputs.kicad_sch, lcsc_bom.xls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]
2022-03-31 Ver 2.0 of board.
    Also major advances in code.
    [inputs.kicad_sch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]
2022-07-27 Version 0.03
    [inputs.kicad_sch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]
2022-08-11 Version .06
    [main_board-B_Cu.gbr, main_board-B_Mask.gbr, main_board-B_Paste.gbr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]
2022-09-05 Version .20
    Moves to external library
    [bonkulator_bom.xlsx, lcsc_bom.xls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]
2022-09-28 Software v2.2
    Removes unneeded files.
    Adds pre-flight handler in WiFi do_server();
    Removes debug printouts.
    [bonkulator_bom.xlsx, inputs.kicad_sch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]
2022-09-28 Delete arduino_secrets.h
    Removes secrets folder
2022-09-29 Updates panel
    [panel.kicad_pcb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]
2022-10-01 Updates monitor circuitry. Sets outputs on init().
    [bonkulator_bom.xlsx, inputs.kicad_sch, lcsc_bom_new.xls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]
2022-10-06 Version .25
    Fixes CV mod of period.
    [bonkulator_bom.xlsx]
2022-10-15 Adds Bonk Daddy
    [BonkDaddyBoard-B_Cu.gbr, BonkDaddyBoard-B_Mask.gbr, BonkDaddyBoard-B_Paste.gbr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]
2022-10-21 Upgrades board to v5. Adds Bonk Daddy.
    [BonkDaddyBoard-B_Cu.gbr, BonkDaddyBoard-B_Mask.gbr, BonkDaddyBoard-B_Paste.gbr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]
2022-10-22 Moves gerber to fab folder.
    [panel.kicad_pcb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]
2022-11-02 Adds 2HP BonkDaddy. Fixes boms/cpl. Updates Readme
    [BonkDaddy2HP_Board-B_Cu.gbr, BonkDaddy2HP_Board-B_Mask.gbr, BonkDaddy2HP_Board-B_Paste.gbr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]
2022-11-06 Getting ready for first major release.
    Adds support for main board v5. Output range adjustment.
    Makes DAC use all 12 bits.
2022-11-09 Reset parameters via web doesn't cut connection
    [Bonkulator.ino]
2022-11-10 Adds USB connector to Bonk Daddy 2HP LCSC bom
    [BonkDaddy2HP_Board.kicad_sch, BonkDaddy2HP_Board.xlsx]
2022-11-16 LED current resistors now 2,.2K
    [inputs.kicad_sch, main_board.csv, main_board.kicad_sch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]
2022-11-19 New waveform structure
    Removes inverse waveforms, adds haystack and pyramid waveforms.
    Fixes Pulse waveform.
    Renames "Period" to "Active Time", "Post Delay" to "Idle Time".
    Extends parameters to use all 16 bits. (Active Time max is now 65535)
    [bonkulator_bom.xlsx]
2022-11-21 Adds debounce caps to trigger inputs
    [bonkulator_bom.xlsx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]
2022-11-23 Adds WiFi indicator to status in terminal mode.
    Also improves status printing.
2022-12-03 Updates main board to 4.1, fixes panel LED that was off center.
    [bonkulator_bom.xlsx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]
2022-12-05 Fix for rotary encoder
    [Rotary_Encoder_fxns.h]
2022-12-09 Update Rotary_Encoder_fxns.h
    Fixes warning about signed - unsigned comparison
    [Rotary_Encoder_fxns.h]
2022-12-09 Adds trigger skip and density
    [BONK_output_fxns.h]
2022-12-10 Update BONK_output_fxns.h
    Makes external clock amendment happen at the correct time.
    [BONK_output_fxns.h]
2022-12-10 Update trigger_fxns.h
    Terminal status correctly prints External clock settings now.
2022-12-10 Update Bonkulator.ino
    Fixes init_all so that parameters are correctly transferred after init.
    [Bonkulator.ino]
2022-12-19 Adds debounce caps to trigger switches
    [bonkulator_bom.xlsx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]
2023-02-02 Fixes Settings bug
    Needed to save selected_fxn before using it in begin()
    [BONK_output_fxns.h]
2023-04-15 Fixes remote trigger commands and idle value for unipolar operation
    [BONK_output_fxns.h, Keyboard_fxns.h, output_cal_fxns.h]
2023-05-08 Makes Idle Value a fixed point variable
    [BONK_output_fxns.h, Keyboard_fxns.h]
2023-05-26 Update BONK_output_fxns.h
    Removes scale correction from set idle value.
    Creates fxn: scale_dac.
    [BONK_output_fxns.h]
2023-06-03 Fixes apply scale and offset.
    [waveform_fxns.h]
2023-06-04 Update output_cal_fxns.h
    Sets +/-5V range. Uses 5V for calibrating scale.
2023-06-08 Uses generate_boms.bat now.
    [BonkDaddy2HP_Board.csv, BonkDaddy2HP_Board.kicad_sch, BonkDaddy2HP_Board.xlsx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]
2023-06-08 Updates main_board, uses generate_boms.bat
    Updates reverse protection circuitry on main board.
    Updates 3.3V reference circuitry.
    Uses generate_boms and retires .xlsx BOM files.
    [bonkulator_bom.xlsx, inputs.kicad_sch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]
2023-07-26 Fix USB Direct when sending refresh cmd.
    [Keyboard_fxns.h]
2023-08-07 Rev 4.2 of board
    [bonkulator_cpl.xlsx, main_board-B_Cu.gbr, main_board-B_Mask.gbr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]
2023-08-11 Adds wifi_toJSON()
    Doesn't send WiFi params to USB.
    [BONK_ui.h]
2023-08-11 Just in case.
    Alternate definition for bool in_wifi()
2023-08-15 Fixes string entry being wrecked by terminal_print_status
    [Bonkulator.ino]
2023-08-28 Updates board to 5.0
    Adds output resistors. Fixes AS431 pinout
    [bonkulator_cpl.xlsx, main_board-B_Cu.gbr, main_board-B_Mask.gbr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]
2023-08-28 Support for new board
    Adds Board Revision selection to settings. Removes need for scaling. Leaves scaling code intact just in case.
2023-09-27 Fixes redeclaration of #define
    [user_waveforms_fxns.h]
2023-09-27 Removes KiCAD logo, moves display outline
    [panel.kicad_pcb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]
2023-10-03 New front panel silkscreen
    [panel.kicad_pcb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]
2023-10-03 Either Way doesn't work
    Saved just in case
    [main_board.csv, main_board.kicad_sch, outputs.kicad_sch]
2023-10-04 Goes to diodes for reverse power protection
    Re-layout for better noise performance.
    [main_board.kicad_sch]
2023-10-22 Fixes trigger LED
2023-10-22 Fixes keyboard bug
    Doing a digitalRead on A2 causes input not to go to zero.
    Using analogRead fixes this.
    [Bonkulator.ino, hardware_fxns.h]
2023-10-22 Fixes keyboard bug
    Using digitalRead on A2 causes inpuit not to go to zero.
    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
    [Keyboard_fxns.h]
2023-10-24 Don't send offset correction with wave data. Not needed.
    [waveform_fxns.h]
2023-10-30 Moves adc scale factor here from input_cal
2023-10-31 Work on Bounce
    Removes CV params.
    Makes scale and offset params use offsets. Now bipolar range.
    Moves calc code from Bonkulator.ino
    Calculates bounce correctly.
    [bounce_fxns.h]
2023-11-02 Improves check_bounce. Adds check_bounce_triggers and reset_inputs.
    [bounce_fxns.h]
2023-11-03 Prints reading to OLED and terminal.
    Also uses one copy of bounce_labels
2023-11-11 Fixes to Bounce fxn.
    [Bonkulator.ino, bounce_fxns.h]
2023-11-11 Fixes path to secrets.h
    [Bonkulator.ino]
2023-11-11 New layout. Fixes regulator chip pinout error.
    [inputs.kicad_sch, main_board.csv, main_board.kicad_sch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]
2023-11-15 Fixes failure to trigger on boot.
    You used to have to go to the desired output before it would trigger properly.
    [BONK_output_fxns.h, Bonkulator.ino]
2023-12-02 Adds download of arduino-cli if it doesn't exist
2023-12-03 Create arduino-cli
    For the Mac
2023-12-03 Uses arduino-cli to list boards.
2023-12-03 Only bumps index on valid boards.
2023-12-05 Uses arduino-cli to compile.
    Removes unneeded cache folder
2023-12-08 Times the make process and prints results in hh:mm:ss format
2024-01-08 Fixes app crash
    Fixes crash in the app when you press a key to restore the display after it has entered screen-saver mode then send a command via the app.
    [BONK_ui.h]
2024-01-08 Updated LED resistors
    [BonkDaddy2HP_Board-B_Cu.gbr, BonkDaddy2HP_Board-B_Mask.gbr, BonkDaddy2HP_Board-B_Paste.gbr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]
2024-01-08 Swaps part for bom.
    # Replace "SK1, " with "U1, " in each field
2024-01-08 Fixes main board.
    Fixes regulator footprint. Re lays out board to improve noise performance. Around -50db now at outputs.
    [inputs.kicad_sch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]
2024-01-09 Updates bom for digi-key
    [inputs.kicad_sch, main_board.csv, main_board.kicad_sch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]
2024-04-04 Fixes bounce function.
    Also stops repeat trigger when altering params.
    [bounce_fxns.h]
2024-04-28 Fixes bug where yes couldn't be set to no by put_param
    input_offsets array was missing last element.
    Removed spaces from variables.
    Used F macro to reduce RAM usage.
    [input_cal_fxns.h]
2024-05-06 Uses new backit and changes
    [config.csv]
2024-05-06 Adds section on Power installation and one on groups.
2024-05-11 Removes backit related files.
    [config.csv]
